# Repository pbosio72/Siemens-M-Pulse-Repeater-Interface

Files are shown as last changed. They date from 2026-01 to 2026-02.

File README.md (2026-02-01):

# Siemens M Pulse Repeater Interface
# Interfaccia per Ripetitore di Impulsi Siemens M

[English](#english) | [Italiano](#italiano)

---

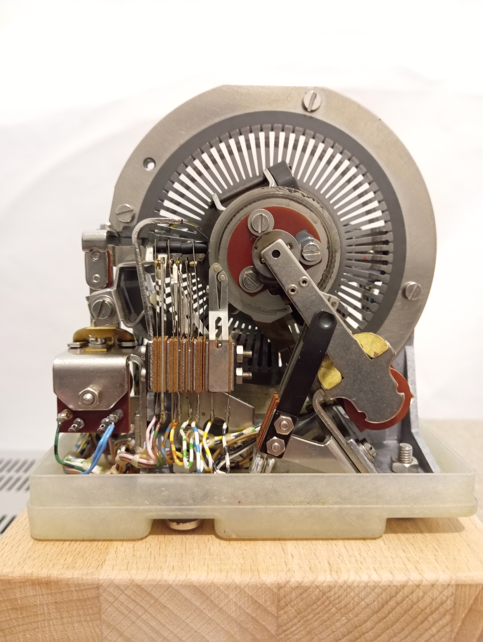
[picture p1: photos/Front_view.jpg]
Siemens Pulse Repeater Front View

*Front view of the Siemens M pulse repeater*

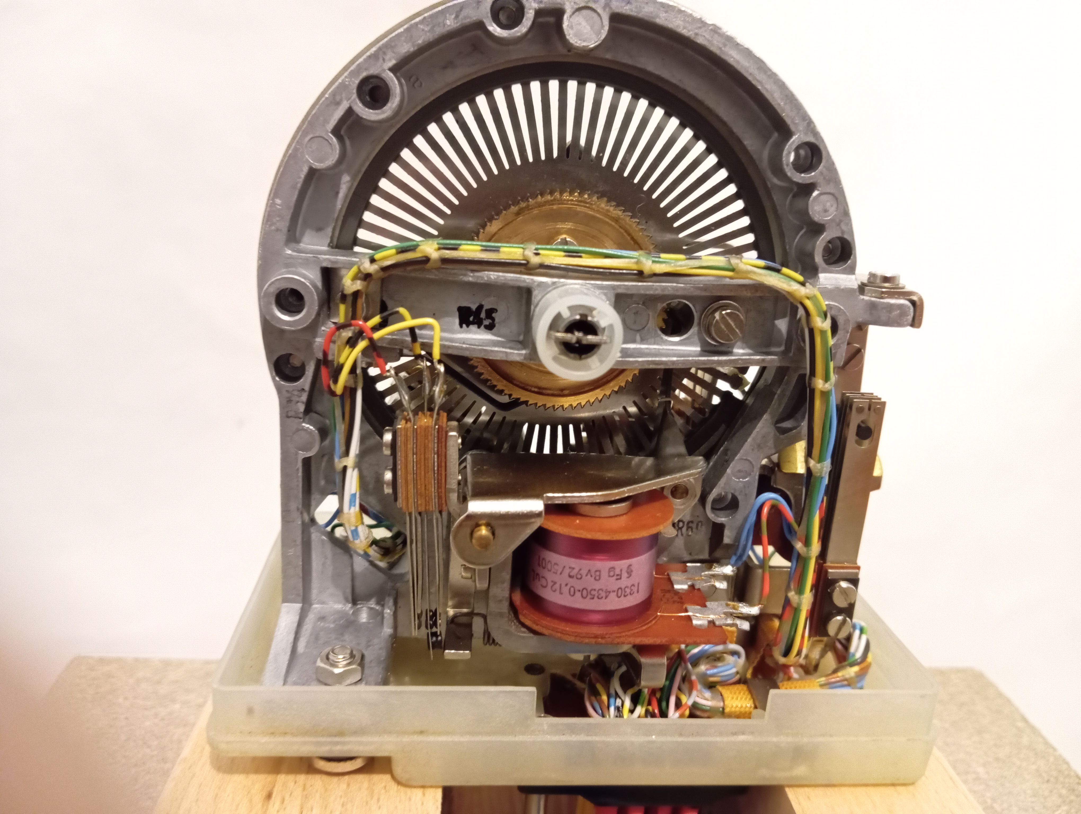
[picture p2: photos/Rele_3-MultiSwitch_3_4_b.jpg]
Siemens Pulse Repeater Rear View

*Rear view showing relays and connections*

---

## English

### Overview
This project documents and provides an interface for the Siemens pulse repeater used in "M System" automatic telephone exchanges. The pulse repeater is an electromechanical memory device that served as a temporary register to store telephone number digits in the form of consecutive pulse trains.

This repository includes:
- Complete pinout mapping and functional logic documentation
- Arduino interface for controlling inputs and reading outputs
- Educational demonstrator using numeric keypad input and display output
- Historical documentation and photographs

### Historical Context
The Siemens pulse repeater was introduced in Italian automatic telephone exchanges (SIP) in 1957 and remained in service until approximately 1975, when electronic exchanges began to replace electromechanical systems. 

This device can be considered an electromechanical FIFO memory or circular shift register. Its ingenious construction uses a rotating metal disk divided into thin lamellae, each capable of two stable positions (comparable to 0 and 1): "behind" or "in front of" a ring-shaped track with a reading contact.

Similar electromechanical memories were used in early computers such as the IBM 602 (1946-48) and the IBM 421 tabulator (1950).

### Project Structure
```
.
├── docs/                    # Documentation and datasheets
│   └── historical/         # Historical documents and references
├── technic/                 # Technical documentation
│   ├── pinout/             # Pin mapping and connections
│   └── components/         # Memory components
├── photos/                  # Photographs of the device
├── arduino/                 # Arduino interface code
│   ├── examples/           # Example sketches
│   └── libraries/          # Custom libraries
└── README.md
```

### Hardware Requirements
- Siemens M Pulse Repeater
- Arduino M0 (or compatible boards: Uno, Mega, Nano, etc.)
- Numeric keypad (input device)
- Display (TBD - output device)
- Interface components (relays, drivers, optoisolators - see hardware documentation)
- Power supply (appropriate voltage for the pulse repeater)

---

## ⚠️ POWER SUPPLY AND SAFETY WARNING

### 🔴 CRITICAL SAFETY INFORMATION - READ BEFORE BUILDING

This system requires **TWO separate power supplies**:

#### 1. LOW VOLTAGE SECTION (5V DC)
- Arduino board
- LCD2004 display
- MCP23017 I2C expander
- Digital signal lines
- Control circuitry

#### 2. HIGH VOLTAGE SECTION (48V DC)
- Relay coils
- Mechanical memory actuation system
- Motor drives

### ELECTRICAL ISOLATION

The 5V and 48V sections **MUST** be electrically isolated:
- Relays provide optical or magnetic isolation between sections
- Arduino controls relay coils (low voltage side)
- Relay contacts switch high voltage power
- **NEVER** connect 48V directly to Arduino pins
- Use optocouplers or relay modules with built-in isolation

### WIRING REQUIREMENTS
- Use appropriate wire gauge for 48V current levels
- Ensure proper insulation on all 48V connections
- Keep 48V wiring separate from 5V signal wiring
- Use terminal blocks or connectors rated for 48V
- Implement proper grounding for safety

---

## ⚡ DANGER - HIGH VOLTAGE WARNING

### 48V DC CAN BE LETHAL UNDER CERTAIN CONDITIONS

- 48V DC can cause electrical shock and serious injury
- Risk increases with wet conditions or broken skin
- Can cause burns, muscle contractions, and cardiac effects
- Always disconnect power before handling circuits
- Use insulated tools when working with live circuits
- Never work on circuits while powered
- Ensure all connections are properly insulated
- Keep work area dry

---

## 📜 DISCLAIMER

**The author(s) of this project DISCLAIM ALL RESPONSIBILITY and LIABILITY for any injury, death, property damage, or other consequences resulting from the construction, modification, or use of this system.**

By building or using this project, you acknowledge that:
- ✓ You understand the risks involved with high voltage systems
- ✓ You have the necessary skills and knowledge to work safely
- ✓ You accept full responsibility for your safety and others
- ✓ You will comply with all local electrical codes and regulations
- ✓ You use this information entirely at your own risk

### ⛔ IF YOU ARE NOT QUALIFIED TO WORK WITH HIGH VOLTAGE SYSTEMS, DO NOT ATTEMPT TO BUILD THIS PROJECT.

Consult a qualified electrician or engineer if you have any doubts about electrical safety or proper construction techniques.

---

## 🛡️ RECOMMENDED SAFETY PRACTICES

1. **ALWAYS** disconnect power before touching any part of the circuit
2. Use a multimeter to verify circuits are de-energized
3. Wait for capacitors to discharge before handling
4. Implement emergency stop switch (easily accessible)
5. Use proper enclosure to prevent accidental contact
6. Label all high voltage sections clearly
7. Use appropriate personal protective equipment (PPE)
8. Never bypass safety interlocks or fuses
9. Keep flammable materials away from electrical components
10. Have fire extinguisher suitable for electrical fires nearby

### COMPONENT RATINGS
- Verify current ratings exceed maximum load
- Use fuses or circuit breakers for overcurrent protection
- Select wire gauge appropriate for current and voltage
- Use connectors and terminals rated for the application

### TESTING PROCEDURE
1. Inspect all connections before applying power
2. Test 5V section first (Arduino and logic circuits)
3. With 48V disconnected, verify relay operation (clicking sound)
4. Connect 48V with load disconnected
5. Measure voltages at all test points
6. Connect load only after verifying all safety checks
7. Monitor system during initial operation

### LOCAL REGULATIONS
- Check local electrical codes and regulations
- Some jurisdictions may require certified installation
- Building permits may be required
- Industrial safety standards may apply (OSHA, IEC, etc.)
- Comply with all applicable laws and standards

---

### Current Status
- ✅ Reverse engineering completed
- ✅ Pinout and functional logic documented
- 🔄 Arduino interface testing in progress
- ⏳ Input/output devices integration (planned)
- ⏳ Educational demonstrator assembly (planned)

### Getting Started
_(Documentation will be added as the project progresses)_

1. Review the pinout documentation in `/technic/pinout/`
2. Check the interface schematics in `/technic/components/`
3. Upload the Arduino sketch from `/arduino/examples/`
4. Connect the hardware according to the wiring diagram
5. Test with the provided examples

### Educational Demonstrator
The final goal is to create an educational demonstrator where:
- **Input:** Data is entered via numeric keypad (simulating telephone dialing)
- **Memory:** The pulse repeater stores the digit sequence
- **Output:** The stored data is displayed on an output device

This demonstrates the working principle of electromechanical memories used in mid-20th century telecommunications.

### Contributing
Contributions are welcome! This project aims to preserve and document historical telecommunications technology. Feel free to:
- Submit improvements to documentation
- Share additional historical information or photographs
- Propose interface enhancements
- Report issues or suggest features

### License
This project is released under an open-source license (TBD).

### References
- Foddis, *Corso teorico-pratico di Telefonia*, 2nd ed., Hoepli, 1972 (pp. 150+)
- Luceri, *Il telefono*, Editoriale Delfino, 1970

### Acknowledgments
This project documents technology developed by Siemens for SIP (Società Italiana per l'Esercizio Telefonico) and used in Italian telephone exchanges from 1957 to approximately 1975.

---

## Italiano

### Panoramica
Questo progetto documenta e fornisce un'interfaccia per il ripetitore di impulsi Siemens utilizzato nelle centrali telefoniche automatiche "sistema M". Il ripetitore di impulsi è un dispositivo di memoria elettromeccanica che fungeva da registro temporaneo per memorizzare le cifre del numero telefonico sotto forma di treni di impulsi consecutivi.

Questo repository include:
- Mappatura completa dei pin e documentazione della logica funzionale
- Interfaccia Arduino per comandare gli input e leggere gli output
- Dimostratore educativo con input da tastierino numerico e output su display
- Documentazione storica e fotografie

### Contesto Storico
Il ripetitore di impulsi Siemens fu introdotto nelle centrali telefoniche automatiche italiane (SIP) nel 1957 e rimase in servizio fino al 1975 circa, quando le centrali elettroniche iniziarono a sostituire i sistemi elettromeccanici.

Questo dispositivo può essere considerato una memoria FIFO elettromeccanica o un registro circolare a scorrimento. La sua costruzione ingegnosa utilizza un disco metallico rotante suddiviso in lamelle sottili, ciascuna capace di due posizioni stabili (paragonabili a 0 e 1): "dietro" o "davanti" ad una pista di forma anulare con un contatto di lettura.

Memorie elettromeccaniche simili furono utilizzate nei primi calcolatori come l'IBM 602 (1946-48) e la tabulatrice IBM 421 (1950).

### Struttura del Progetto
```
.
├── docs/                    # Documentazione e datasheet
│   └── historical/         # Documenti storici e riferimenti
├── technic/                 # Documentazione tecnica
│   ├── pinout/             # Mappatura pin e collegamenti
│   └── components/         # Componenti della memoria
├── photos/                  # Fotografie del dispositivo
├── arduino/                 # Codice interfaccia Arduino
│   ├── examples/           # Sketch di esempio
│   └── libraries/          # Librerie personalizzate
└── README.md
```

### Requisiti Hardware
- Ripetitore di Impulsi Siemens M
- Arduino M0 (o schede compatibili: Uno, Mega, Nano, ecc.)
- Tastierino numerico (dispositivo di input)
- Display (da definire - dispositivo di output)
- Componenti di interfaccia (relè, driver, optoisolatori - vedi documentazione hardware)
- Alimentatore (tensione appropriata per il ripetitore di impulsi)

---

## ⚠️ ALIMENTAZIONE E AVVISO DI SICUREZZA

### 🔴 INFORMAZIONI CRITICHE DI SICUREZZA - LEGGERE PRIMA DI COSTRUIRE

Questo sistema richiede **DUE alimentazioni separate**:

#### 1. SEZIONE A BASSA TENSIONE (5V DC)
- Scheda Arduino
- Display LCD2004
- Espansore I2C MCP23017
- Linee di segnale digitali
- Circuiti di controllo

#### 2. SEZIONE AD ALTA TENSIONE (48V DC)
- Bobine dei relè
- Sistema di attuazione della memoria meccanica
- Azionamenti motori

### ISOLAMENTO ELETTRICO

Le sezioni a 5V e 48V **DEVONO** essere elettricamente isolate:
- I relè forniscono isolamento ottico o magnetico tra le sezioni
- Arduino controlla le bobine dei relè (lato bassa tensione)
- I contatti dei relè commutano l'alimentazione ad alta tensione
- **MAI** collegare i 48V direttamente ai pin di Arduino
- Utilizzare optoisolatori o moduli relè con isolamento integrato

### REQUISITI DI CABLAGGIO
- Utilizzare sezione del cavo appropriata per i livelli di corrente a 48V
- Assicurare un adeguato isolamento su tutte le connessioni a 48V
- Mantenere il cablaggio a 48V separato da quello dei segnali a 5V
- Utilizzare morsettiere o connettori certificati per 48V
- Implementare una corretta messa a terra per la sicurezza

---

## ⚡ PERICOLO - AVVISO ALTA TENSIONE

### 48V DC POSSONO ESSERE LETALI IN DETERMINATE CONDIZIONI

- 48V DC possono causare shock elettrico e gravi lesioni
- Il rischio aumenta in condizioni di umidità o con pelle non integra
- Possono causare ustioni, contrazioni muscolari ed effetti cardiaci
- Scollegare sempre l'alimentazione prima di manipolare i circuiti
- Utilizzare utensili isolati quando si lavora con circuiti sotto tensione
- Non lavorare mai su circuiti alimentati
- Assicurarsi che tutte le connessioni siano adeguatamente isolate
- Mantenere l'area di lavoro asciutta

---

## 📜 DISCLAIMER

**L'autore/gli autori di questo progetto DECLINANO OGNI RESPONSABILITÀ per qualsiasi lesione, morte, danno alla proprietà o altre conseguenze derivanti dalla costruzione, modifica o utilizzo di questo sistema.**

Costruendo o utilizzando questo progetto, riconosci che:
- ✓ Comprendi i rischi connessi ai sistemi ad alta tensione
- ✓ Possiedi le competenze e le conoscenze necessarie per lavorare in sicurezza
- ✓ Ti assumi la piena responsabilità per la tua sicurezza e quella degli altri
- ✓ Rispetterai tutte le normative elettriche locali
- ✓ Utilizzi queste informazioni interamente a tuo rischio

### ⛔ SE NON SEI QUALIFICATO PER LAVORARE CON SISTEMI AD ALTA TENSIONE, NON TENTARE DI COSTRUIRE QUESTO PROGETTO.

Consulta un elettricista o ingegnere qualificato in caso di dubbi sulla sicurezza elettrica o sulle corrette tecniche di costruzione.

---

## 🛡️ PRATICHE DI SICUREZZA RACCOMANDATE

1. **SEMPRE** scollegare l'alimentazione prima di toccare qualsiasi parte del circuito
2. Utilizzare un multimetro per verificare che i circuiti siano de-energizzati
3. Attendere la scarica dei condensatori prima della manipolazione
4. Implementare un interruttore di emergenza (facilmente accessibile)
5. Utilizzare un involucro adeguato per prevenire contatti accidentali
6. Etichettare chiaramente tutte le sezioni ad alta tensione
7. Utilizzare dispositivi di protezione individuale (DPI) appropriati
8. Non bypassare mai gli interblocchi di sicurezza o i fusibili
9. Tenere materiali infiammabili lontani dai componenti elettrici
10. Avere un estintore adatto a incendi elettrici nelle vicinanze

### CARATTERISTICHE DEI COMPONENTI
- Verificare che le correnti nominali superino il carico massimo
- Utilizzare fusibili o interruttori automatici per la protezione da sovracorrente
- Selezionare la sezione del cavo appropriata per corrente e tensione
- Utilizzare connettori e terminali certificati per l'applicazione

### PROCEDURA DI TEST
1. Ispezionare tutte le connessioni prima di applicare l'alimentazione
2. Testare prima la sezione a 5V (Arduino e circuiti logici)
3. Con i 48V scollegati, verificare il funzionamento dei relè (suono di scatto)
4. Collegare i 48V con il carico scollegato
5. Misurare le tensioni in tutti i punti di test
6. Collegare il carico solo dopo aver verificato tutti i controlli di sicurezza
7. Monitorare il sistema durante il funzionamento iniziale

### NORMATIVE LOCALI
- Verificare i codici e le normative elettriche locali
- Alcune giurisdizioni potrebbero richiedere installazione certificata
- Potrebbero essere necessari permessi di costruzione
- Potrebbero applicarsi standard di sicurezza industriale (OSHA, IEC, ecc.)
- Rispettare tutte le leggi e gli standard applicabili

---

### Stato Attuale
- ✅ Reverse engineering completato
- ✅ Pinout e logica funzionale documentati
- 🔄 Test interfaccia Arduino in corso
- ⏳ Integrazione dispositivi input/output (pianificata)
- ⏳ Assemblaggio dimostratore educativo (pianificato)

### Come Iniziare
_(La documentazione verrà aggiunta man mano che il progetto progredisce)_

1. Consultare la documentazione del pinout in `/technic/pinout/`
2. Verificare gli schemi dell'interfaccia in `/technic/components/`
3. Caricare lo sketch Arduino da `/arduino/examples/`
4. Collegare l'hardware secondo lo schema di cablaggio
5. Testare con gli esempi forniti

### Dimostratore Educativo
L'obiettivo finale è creare un dimostratore educativo dove:
- **Input:** I dati vengono inseriti tramite tastierino numerico (simulando la composizione telefonica)
- **Memoria:** Il ripetitore di impulsi memorizza la sequenza di cifre
- **Output:** I dati memorizzati vengono visualizzati su un dispositivo di output

Questo dimostra il principio di funzionamento delle memorie elettromeccaniche utilizzate nelle telecomunicazioni della metà del XX secolo.

### Contribuire
I contributi sono benvenuti! Questo progetto mira a preservare e documentare la tecnologia storica delle telecomunicazioni. Sentitevi liberi di:
- Inviare miglioramenti alla documentazione
- Condividere informazioni storiche o fotografie aggiuntive
- Proporre miglioramenti all'interfaccia
- Segnalare problemi o suggerire funzionalità

### Licenza
Questo progetto è rilasciato sotto licenza open-source (da definire).

### Riferimenti
- Foddis, *Corso teorico-pratico di Telefonia*, 2a ed., Hoepli, 1972 (pag. 150 e seguenti)
- Luceri, *Il telefono*, Editoriale Delfino, 1970

### Riconoscimenti
Questo progetto documenta la tecnologia sviluppata da Siemens per la SIP (Società Italiana per l'Esercizio Telefonico) e utilizzata nelle centrali telefoniche italiane dal 1957 al 1975 circa.

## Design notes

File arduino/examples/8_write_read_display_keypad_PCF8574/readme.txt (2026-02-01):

=============================================================================
MECHANICAL MEMORY SYSTEM WITH KEYPAD INPUT - README
=============================================================================

Sketch Name: 8_write_read_display_keypad_PCF8574.ino
Version: 1.0
Date: 2026-02-01
Description: Complete mechanical memory system with 3x4 keypad input via PCF8574

=============================================================================
OVERVIEW
=============================================================================

This sketch implements a complete mechanical memory system with 3x4 matrix keypad
input. Numbers (0-9) are entered via the keypad, converted to 4-bit BCD sequences,
and stored mechanically on a rotating disk. The system uses a PCF8574 I2C expander
to handle the keypad matrix, freeing up Arduino pins for other components.

Key Features:
- 3x4 matrix keypad input via PCF8574 I2C expander (8 I/O pins)
- Real-time digit entry and immediate writing to mechanical memory
- Number to binary (BCD) conversion with 4 bits per digit
- Real-time read and decode display on LCD2004
- Automatic system initialization and head positioning
- Write protection through controlled workflow
- Professional LCD display with status messages
- Visual effects with sliding text and progress indicators

Key Differences from Previous Versions:
- Replaces push buttons with 3x4 matrix keypad
- Uses PCF8574 I2C expander (simpler and cheaper than MCP23017)
- Implements custom keypad scanning function with bitwise operations
- Real-time digit display during read operation
- Enhanced user interface with clear status messages
- Improved timing constants for better user experience
- Removed Serial Monitor dependency (optional debug only)

=============================================================================
POWER SUPPLY AND SAFETY WARNING
=============================================================================

CRITICAL SAFETY INFORMATION - READ BEFORE BUILDING

This system requires TWO separate power supplies:

1. LOW VOLTAGE SECTION (5V DC):
   - Arduino board
   - LCD2004 display
   - MCP23017 I2C expander
   - Digital signal lines
   - Control circuitry

2. HIGH VOLTAGE SECTION (48V DC):
   - Relay coils
   - Mechanical memory actuation system
   - Motor drives

ELECTRICAL ISOLATION:
The 5V and 48V sections MUST be electrically isolated:
- Relays provide optical or magnetic isolation between sections
- Arduino controls relay coils (low voltage side)
- Relay contacts switch high voltage power
- NEVER connect 48V directly to Arduino pins
- Use optocouplers or relay modules with built-in isolation

WIRING REQUIREMENTS:
- Use appropriate wire gauge for 48V current levels
- Ensure proper insulation on all 48V connections
- Keep 48V wiring separate from 5V signal wiring
- Use terminal blocks or connectors rated for 48V
- Implement proper grounding for safety

** DANGER - HIGH VOLTAGE WARNING **
=============================================================================
48V DC CAN BE LETHAL UNDER CERTAIN CONDITIONS

- 48V DC can cause electrical shock and serious injury
- Risk increases with wet conditions or broken skin
- Can cause burns, muscle contractions, and cardiac effects
- Always disconnect power before handling circuits
- Use insulated tools when working with live circuits
- Never work on circuits while powered
- Ensure all connections are properly insulated
- Keep work area dry

DISCLAIMER:
The author(s) of this project DISCLAIM ALL RESPONSIBILITY and LIABILITY
for any injury, death, property damage, or other consequences resulting
from the construction, modification, or use of this system.

By building or using this project, you acknowledge that:
- You understand the risks involved with high voltage systems
- You have the necessary skills and knowledge to work safely
- You accept full responsibility for your safety and others
- You will comply with all local electrical codes and regulations
- You use this information entirely at your own risk

IF YOU ARE NOT QUALIFIED TO WORK WITH HIGH VOLTAGE SYSTEMS,
DO NOT ATTEMPT TO BUILD THIS PROJECT.

Consult a qualified electrician or engineer if you have any doubts
about electrical safety or proper construction techniques.
=============================================================================

RECOMMENDED SAFETY PRACTICES:

1. ALWAYS disconnect power before touching any part of the circuit
2. Use a multimeter to verify circuits are de-energized
3. Wait for capacitors to discharge before handling
4. Implement emergency stop switch (easily accessible)
5. Use proper enclosure to prevent accidental contact
6. Label all high voltage sections clearly
7. Use appropriate personal protective equipment (PPE)
8. Never bypass safety interlocks or fuses
9. Keep flammable materials away from electrical components
10. Have fire extinguisher suitable for electrical fires nearby

COMPONENT RATINGS:
- Verify current ratings exceed maximum load
- Use fuses or circuit breakers for overcurrent protection
- Select wire gauge appropriate for current and voltage
- Use connectors and terminals rated for the application

TESTING PROCEDURE:
1. Inspect all connections before applying power
2. Test 5V section first (Arduino and logic circuits)
3. With 48V disconnected, verify relay operation (clicking sound)
4. Connect 48V with load disconnected
5. Measure voltages at all test points
6. Connect load only after verifying all safety checks
7. Monitor system during initial operation

LOCAL REGULATIONS:
- Check local electrical codes and regulations
- Some jurisdictions may require certified installation
- Building permits may be required
- Industrial safety standards may apply (OSHA, IEC, etc.)
- Comply with all applicable laws and standards

=============================================================================
HARDWARE REQUIREMENTS
=============================================================================

Components:
- Arduino Uno (or compatible)
- LCD2004 Display (20x4 with I2C module, address 0x27)
- PCF8574 I2C expander (address 0x20)
- 3x4 Matrix Keypad
- 3 Relays (for mechanical memory actuation)
- 2 Position Switches (CCW limit and read head sensor)
- Mechanical memory disk and head assembly

Pin Configuration:

ARDUINO UNO:
  Digital Pin 6  → Switch A (reserved for future use)
  Digital Pin 7  → Switch B (reserved for future use)
  Digital Pin 8  → Switch C (CCW limit sensor)
  Digital Pin 9  → Read Head Switch
  Digital Pin 10 → Relay 1 (Write bit 1 mechanism)
  Digital Pin 11 → Relay 2 (Head rotation control)
  Digital Pin 12 → Relay 3 (Disk rotation control)
  Arduino UNO
    Analog Pin A4  → I2C SDA (LCD + MCP23017)
    Analog Pin A5  → I2C SCL (LCD + MCP23017)
  Arduino MEGA 2560
    Digital Pin 20  → I2C SDA (LCD + MCP23017)
    Digital Pin 21  → I2C SCL (LCD + MCP23017)
  Arduino M0
    Dedicated Pin

I2C DEVICES:
  LCD2004:  Address 0x27, connected to SDA/SCL
  PCF8574:  Address 0x20, connected to SDA/SCL

3X4 KEYPAD → PCF8574:
Pin out inverted for montability reason
  Physical Pin 1 → P6 (Column 2: keys 2, 5, 8, 0)
  Physical Pin 2 → P5 (Row 1: keys 1, 2, 3)
  Physical Pin 3 → P4 (Column 1: keys 1, 4, 7, *)
  Physical Pin 4 → P3 (Row 4: keys *, 0, #)
  Physical Pin 5 → P2 (Column 3: keys 3, 6, 9, #)
  Physical Pin 6 → P1 (Row 3: keys 7, 8, 9)
  Physical Pin 7 → P0 (Row 2: keys 4, 5, 6)

KEYPAD MATRIX:
       C1(P2)  C2(P0)  C3(P4)
R1(P1)   1        2        3
R2(P6)   4        5        6
R3(P5)   7        8        9
R4(P3)   *        0        #

NOTE: The keypad pin mapping was determined through physical testing with
      a multimeter in continuity mode. Your keypad may have different wiring.

WHY PCF8574 INSTEAD OF MCP23017:
The PCF8574 is more suitable for this project because:
- 8 I/O pins are sufficient (keypad needs only 7 pins)
- Simpler to use (no pin mode configuration needed)
- More cost-effective (~1€ vs ~2-3€)
- Lower power consumption
- Adequate speed for keypad scanning
- Built-in pull-up resistors
The MCP23017 (16 I/O) would be oversized for this application.

=============================================================================
SOFTWARE REQUIREMENTS
=============================================================================

Arduino Libraries (install via Library Manager):
- Wire.h (built-in)
- LiquidCrystal_I2C by Frank de Brabander
- PCF8574 library by Rob Tillaart

Arduino IDE: 1.8.x or 2.x

Installation Steps:
1. Open Arduino IDE
2. Go to Sketch → Include Library → Manage Libraries
3. Search for "LiquidCrystal I2C" and install (by Frank de Brabander)
4. Search for "PCF8574" and install (by Rob Tillaart)
5. Wire.h is included automatically (built-in library)

=============================================================================
HOW IT WORKS
=============================================================================

NUMBER ENCODING (BCD - Binary-Coded Decimal)
Each decimal digit (0-9) is converted to 4 bits:
  0 → 0000    5 → 0101
  1 → 0001    6 → 0110
  2 → 0010    7 → 0111
  3 → 0011    8 → 1000
  4 → 0100    9 → 1001

Example: User enters "102"
  1 → 0001
  0 → 0000
  2 → 0010
  Result stored in memory: 000100000010 (12 bits total)

KEYPAD SCANNING MECHANISM:
The system uses matrix scanning to detect keypresses with PCF8574:
1. All 8 pins are written simultaneously using pcf.write8()
2. Each row is activated (set LOW) one at a time using bitwise operations
3. All columns are read simultaneously using pcf.read8()
4. If a column reads LOW while a row is active, that key is pressed
5. Key position is determined by row-column intersection
6. Debouncing prevents multiple triggers from single press

PCF8574 ADVANTAGES FOR KEYPAD SCANNING:
- Built-in pull-up resistors (no external resistors needed)
- 8-bit read/write operations are atomic (no timing issues)
- Simple bitwise manipulation for row activation
- Adequate speed for human input (no latency issues)
- Interrupt capability available (not used in this implementation)

WRITE PROCESS:
1. System auto-initializes and positions head at CCW (counter-clockwise) block
2. User presses numeric keys (0-9) on keypad
3. LCD displays "Input Sequence" with digits as they are entered
4. Each digit is IMMEDIATELY converted to 4 bits and written to memory
5. Display shows progress: "X/15" (current digit / maximum)
6. Maximum 15 digits can be entered (60 bits total)
7. User can press * at any time to reset and start over

IMMEDIATE WRITE OPERATION:
Unlike previous versions that stored digits then wrote them all at once,
this version writes each digit to memory immediately after entry:
- Press "1" → converts to 0001 → writes 4 bits → done
- Press "0" → converts to 0000 → writes 4 bits → done
- Press "2" → converts to 0010 → writes 4 bits → done
This prevents data loss and provides instant feedback.

READ PROCESS:
1. User presses # key to initiate read
2. System performs finalization moves:
   - Extra disk rotation to complete last write
   - Head moves back one position for alignment
3. LCD displays "Read Data" with "-> " prompt
4. System reads bits from memory sequentially
5. Every 4 bits are decoded to a decimal digit
6. Decoded digit appears on LCD IMMEDIATELY (real-time display)
7. Digits fill the display left-to-right, line by line
8. Display shows "Done" when read completes
9. System returns to input mode

REAL-TIME DECODE DISPLAY:
The read operation displays decoded numbers as they are read:
  Line 0: "     Read Data"
  Line 2: "-> 0123456789012"  (digits appear one by one)
  Line 3: "                Done"

Maximum 17 digits can be displayed on line 2 (20 chars - "-> " = 17)
If more digits exist, they wrap to line 3.

RESET FUNCTION (* key):
1. Displays "Reset System" message
2. Repositions head to CCW block (same as startup)
3. Clears all entered digits
4. Resets digit counter
5. Displays welcome screen
6. Returns to input mode

MECHANICAL SYNCHRONIZATION:
After the last digit is entered and before reading:
  activateRele(rele_3, sleep_time_rotate);  // Extra disk rotation
  activateRele(rele_2, sleep_time_read);    // Head back one position
This compensates for positioning offset during write operations and
ensures the read head is aligned properly with the first stored bit.

=============================================================================
USAGE INSTRUCTIONS
=============================================================================

STEP 1: Power Up & Initialization
- Connect Arduino to power
- LCD displays "System starting..."
- System automatically positions head to CCW block
- LCD shows "Reset System" during positioning
- LCD displays "Siemens Memory Ready" when complete
- After 3 seconds, shows:
    Line 0: "   Input Sequence"
    Line 2: "Enter digits 0-9"
    Line 3: " *->Reset    #->Read"
- System is now ready for input

STEP 2: Enter Numbers (Keys 0-9)
- Press any digit key (0-9) on keypad
- LCD updates to show:
    Line 0: "   Input Sequence"
    Line 1: "-> [your digits]"
    Line 3: "Writing Memory..."
- Digit is immediately written to memory (4 bits)
- Progress indicator appears: "X/15"
- Continue entering digits (maximum 15)
- Each digit is written immediately - no need to press "enter"

Example sequence for entering "1234":
  Press 1 → LCD shows "-> 1" → writes 0001 to memory → shows "1/15"
  Press 2 → LCD shows "-> 12" → writes 0010 to memory → shows "2/15"
  Press 3 → LCD shows "-> 123" → writes 0011 to memory → shows "3/15"
  Press 4 → LCD shows "-> 1234" → writes 0100 to memory → shows "4/15"

STEP 3: Reset System (Key *)
- Press * at any time to reset
- LCD displays "Reset System"
- Head returns to CCW position
- All entered digits are cleared
- System returns to input mode
- Use this to start over with a new number

STEP 4: Read Data (Key #)
- After entering digits, press # to read
- LCD clears and shows "Read Data"
- System performs alignment moves (disk forward, head back)
- Digits appear one by one on Line 2: "-> 0123456789"
- Each group of 4 bits is decoded and displayed immediately
- Watch the digits appear in real-time as memory is read
- After read completes, "Done" appears on Line 3
- Display shows result for 5 seconds
- System automatically returns to input mode for next sequence

STEP 5: Decode Output (Automatic)
The system automatically decodes 4-bit sequences to decimal:
  Memory: 0001 0000 0010
  Display: "-> 102"
No manual decoding needed - digits appear correctly on LCD.

=============================================================================
LCD DISPLAY MESSAGES
=============================================================================

Startup & Initialization:
"System starting..."       - Arduino boot sequence
"Reset System"             - Positioning head to start
"Siemens Memory Ready"     - System initialized (sliding text effect)
"Enter digits 0-9"         - Instructions
" *->Reset    #->Read"     - Key functions

Input Mode:
"   Input Sequence"        - Main header during input
"-> [digits]"              - Shows entered digits (line 1)
"Writing Memory..."        - Brief status during write
"X/15"                     - Progress indicator (X = current, 15 = max)
"Max digits reached!"      - Cannot enter more than 15 digits

Reset Operation:
"Reset System"             - System is resetting
(then returns to startup sequence)

Read Operation:
"     Read Data"           - Read operation header
"-> [decoded digits]"      - Decoded numbers appear here
"                Done"     - Read operation complete

Error Messages:
"No data available!"       - Attempted read with disk at end position
"No data to read!"         - Pressed # without entering any digits
"PCF8574 ERROR!"          - PCF8574 not detected (halts execution)

=============================================================================
CONFIGURATION PARAMETERS
=============================================================================

Timing Constants (in milliseconds):
  sleep_time_rotate = 100;  // Disk rotation timing
  sleep_time_write = 100;   // Write operation timing
  sleep_time_read = 100;    // Read operation timing
  delay_small = 200;        // Text display sliding effect
  delay_medium = 2000;      // Status message duration
  delay_long = 3000;        // Important message duration
  delay_huge = 5000;        // Final result display duration

Tuning the Timing Constants:
- sleep_time_* values control mechanical relay actuation
  - Increase if bits are unreliable or mechanisms are slow
  - Decrease for faster operation (after confirming reliability)
  - Typical range: 50-200ms depending on hardware
- delay_* values control LCD message display duration
  - Adjust for preferred user interface speed
  - delay_small affects sliding text speed (character-by-character)
  - delay_huge affects how long final results are shown

Memory Configuration:
  const int max_numbers = 15;  // Maximum digits (15 × 4 = 60 bits)

I2C Addresses:
  LCD2004:  0x27 (or 0x3F for some modules)
  PCF8574:  0x20 (default, configurable with A0/A1/A2 jumpers)

To change LCD address (if 0x27 doesn't work):
  LiquidCrystal_I2C lcd(0x3F, 20, 4);

To change PCF8574 address:
  PCF8574 pcf(0x21);  // Change 0x20 to desired address

Keypad Pin Mapping:
  byte rowPins[ROWS] = {1, 6, 5, 3};  // P1, P6, P5, P3
  byte colPins[COLS] = {2, 0, 4};     // P2, P0, P4

NOTE: These pin assignments are based on physical testing of a specific
      keypad. Different keypad models may have different internal wiring.
      Use a multimeter to verify your keypad's pin configuration.

=============================================================================
TECHNICAL DETAILS
=============================================================================

BINARY CONVERSION ALGORITHM:
The digitToBits() function extracts 4 bits using bitwise operations:
  bits[0] = (num >> 3) & 1;  // Bit 3 (MSB) - weight 8
  bits[1] = (num >> 2) & 1;  // Bit 2 - weight 4
  bits[2] = (num >> 1) & 1;  // Bit 1 - weight 2
  bits[3] = num & 1;         // Bit 0 (LSB) - weight 1

Example for digit 5 (binary 0101):
  5 >> 3 = 0, masked = 0  →  bits[0] = 0
  5 >> 2 = 1, masked = 1  →  bits[1] = 1
  5 >> 1 = 2, masked = 0  →  bits[2] = 0
  5 >> 0 = 5, masked = 1  →  bits[3] = 1
Result: [0, 1, 0, 1] which is 0101 in binary = 5 in decimal

DECODE ALGORITHM (Read Operation):
The readAndDecodeMemory() function converts 4 bits back to decimal:
  for (int j = 0; j < 4; j++) {
    if (fourBits.charAt(j) == '1') {
      decimalValue += (1 << (3 - j));
    }
  }

Example decoding "0101":
  j=0: '0' → skip
  j=1: '1' → add (1 << 2) = 4 → decimalValue = 4
  j=2: '0' → skip
  j=3: '1' → add (1 << 0) = 1 → decimalValue = 5
Result: 5

KEYPAD MATRIX SCANNING:
The scanKeypad() function implements matrix scanning with PCF8574:
1. Prepare byte pattern with all pins HIGH except current row
2. Write pattern to PCF8574 using pcf.write8()
3. Read all pins simultaneously using pcf.read8()
4. Check column pins using bitRead() to detect LOW state
5. If column is LOW, key at (row, column) is pressed
6. Return corresponding character from keys[][] array
7. If no key pressed, return 0

PCF8574 BITWISE OPERATIONS:
  byte rowPattern = 0xFF;              // All pins HIGH (11111111)
  bitClear(rowPattern, rowPins[r]);   // Set row pin LOW
  pcf.write8(rowPattern);             // Write to all 8 pins at once
  byte readValue = pcf.read8();       // Read all 8 pins at once
  if (bitRead(readValue, colPins[c]) == LOW)  // Check column pin

This approach is more efficient than individual pinMode/digitalWrite calls.

Debouncing is implemented by:
- Waiting for key release before returning
- Adding 50ms delay after release
- 5ms stabilization delay between row changes

READ LOGIC INVERSION:
The read head switch uses inverted logic:
  char bit = (!switchState_read) ? '1' : '0';
This is because the mechanical sensor reads:
  HIGH → bit 0
  LOW  → bit 1
So we invert in software to get correct bit values.

WRITE COMPENSATION:
After entering all digits and before reading:
  activateRele(rele_3, sleep_time_rotate);  // Extra disk rotation
  activateRele(rele_2, sleep_time_read);    // Head back one position

This two-step compensation ensures:
1. The last written bit is properly positioned
2. The read head aligns with the first bit for accurate reading

IMMEDIATE WRITE BEHAVIOR:
Each digit is written as soon as its key is pressed:
  writeDigitToMemory(key);  // Called immediately in loop()
This means:
- Data is never lost (written instantly, not buffered)
- User gets immediate feedback via relay sounds
- No need for a separate "write" or "enter" button
- System state is always synchronized with display

=============================================================================
TROUBLESHOOTING
=============================================================================

Problem: "PCF8574 ERROR!" on LCD at startup
Solution:
  - Check PCF8574 power connections (VCC to 5V, GND to GND)
  - Verify I2C connections (SDA to A4, SCL to A5 on Uno)
  - Check I2C address (default 0x20)
  - Run I2C scanner sketch to detect PCF8574
  - Verify PCF8574 is properly seated if using breadboard
  - Check for solder bridges if using custom PCB
  - Verify A0/A1/A2 address pins configuration

Problem: LCD shows text but no keypad response
Solution:
  - Verify keypad is connected to correct PCF8574 pins
  - Check rowPins[] and colPins[] arrays match your keypad
  - Use multimeter to test keypad pin mapping
  - Add debug Serial.print() to scanKeypad() function
  - Test PCF8574 with simple write8/read8 operations
  - Verify built-in pull-ups are working (no external needed)

Problem: Keypad registers wrong keys
Solution:
  - Your keypad has different internal wiring
  - Use multimeter in continuity mode to map pins
  - Update rowPins[] and colPins[] arrays accordingly
  - Update keys[][] array if button layout differs
  - Refer to "Keypad Pin Mapping" section in header

Problem: Keypad registers multiple keys per press
Solution:
  - Increase debounce delay in scanKeypad()
  - Check for electrical noise on connections
  - Add small capacitors (0.1µF) across keypad pins if needed
  - PCF8574 has built-in pull-ups, no external resistors needed
  - Reduce scan speed (increase delay between pcf.write8() and pcf.read8())

Problem: LCD backlight on but no text
Solution:
  - Adjust contrast potentiometer on I2C module
  - Use small screwdriver on blue component on back
  - Turn slowly until text appears
  - Try changing I2C address to 0x3F

Problem: System doesn't reset properly
Solution:
  - Check Switch C (CCW limit sensor) is working
  - Verify switch is normally-open type
  - Check wiring and connections
  - Add debug prints to see switch state
  - Manually position head and restart
  - Increase sleep_time_rotate if mechanism is slow

Problem: Incorrect bits read from memory
Solution:
  - Increase sleep_time_read and sleep_time_rotate
  - Verify read head switch alignment
  - Check inverted logic is correct (!switchState_read)
  - Ensure smooth mechanical movement
  - Add delays between operations
  - Verify write compensation moves are executing

Problem: Not all digits displayed during read
Solution:
  - LCD can show ~17 digits on line 2 (20 chars - "-> ")
  - If entering 15 digits, some will wrap to line 3
  - This is normal behavior
  - Reduce number of input digits if full visibility needed
  - Check Serial Monitor for complete sequence

Problem: "Max digits reached!" appears
Solution:
  - This is normal - 15 digit limit has been reached
  - Press * to reset and start new sequence
  - Or press # to read current sequence
  - Adjust max_numbers constant if more digits needed
  - Consider mechanical memory capacity before increasing

Problem: "No data to read!" message
Solution:
  - You pressed # without entering any digits first
  - Enter digits 0-9 before pressing #
  - System prevents reading empty memory

=============================================================================
CODE STRUCTURE
=============================================================================

Main Functions:

Keypad Functions:
- scanKeypad()         : Scan 3x4 matrix and return pressed key

Memory Functions:
- activateRele()       : Pulse relay on/off with timing
- digitToBits()        : Convert decimal digit to 4-bit binary array
- writeSingleBit()     : Write one bit to mechanical memory
- writeDigitToMemory() : Convert digit to bits and write all 4

Display Functions:
- printSlow()          : Display text character-by-character (effect)

System Functions:
- resetSystem()        : Clear sequence and reposition head to CCW
- readAndDecodeMemory(): Read bits and decode to decimal in real-time

Setup Section:
- Initialize all pins (Arduino digital pins)
- Initialize LCD2004 display
- Initialize PCF8574 I2C expander
- Set all PCF8574 pins HIGH initially (ready for keypad scanning)
- Perform initial system reset and head positioning

Loop Section:
- Continuously scan keypad for input
- Handle numeric keys (0-9): add to sequence and write to memory
- Handle * key: reset system
- Handle # key: finalize write and read/decode memory
- Update LCD display with current status
- Implement digit counter and maximum limit

Key Variables:
- inputSequence: String storing entered decimal digits
- digitCount: Counter for number of digits entered
- fourBits: Buffer for accumulating 4 bits during read

=============================================================================
NOTES
=============================================================================

- Maximum 15 decimal digits can be stored (60 bits total)
- LCD2004 can display approximately 17 digits per line
- Only digits 0-9 are supported (alphabetic characters not implemented)
- Each digit is written immediately upon entry (no buffering)
- Keypad pin mapping is specific to tested hardware - verify with multimeter
- System automatically handles write/read synchronization
- PCF8574 shares I2C bus with LCD - different addresses prevent conflicts
- PCF8574 has built-in pull-up resistors - no external resistors needed
- Mechanical timing may require adjustment for different hardware
- Both LCD and Serial Monitor show operation status
- Real-time decode provides instant feedback on stored data

=============================================================================
SUPPORT & ADDITIONAL INFORMATION
=============================================================================

For questions, issues, or improvements:
- Review main project README.md in repository root
- Check wiring diagram in /docs folder
- Test PCF8574 separately with simple I2C scanner
- Verify keypad pin mapping with multimeter
- Test mechanical system independently
- Use Serial Monitor for debugging
- Adjust timing constants for your specific hardware

Keypad Pin Testing Procedure:
1. Set multimeter to continuity mode (beep)
2. Place one probe on keypad pin
3. Place other probe on another keypad pin
4. Press each key systematically
5. Note which key makes the beep for each pin pair
6. Build a matrix showing row/column relationships
7. Update rowPins[] and colPins[] arrays accordingly

I2C Device Testing:
1. Upload I2C scanner sketch to Arduino
2. Open Serial Monitor at 9600 baud
3. Should detect devices at 0x20 (PCF8574) and 0x27 (LCD)
4. If addresses differ, update code accordingly

=============================================================================

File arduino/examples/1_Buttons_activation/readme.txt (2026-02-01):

Buttons activation

**File:** 1_Buttons_activation.ino`

**Purpose:** This is the simplest sketch, providing basic button-to-relay mapping without any display or additional feedback mechanisms.

**Hardware Requirements:**
- 3 push buttons (pins 3, 4, 5)
- 3 relays (pins 10, 11, 12)

**Functionality:**
- **Button 1:** Directly controls Relay 1 (ON when pressed, OFF when released)
- **Button 2:** Directly controls Relay 2 (ON when pressed, OFF when released)
- **Button 3:** Directly controls Relay 3 (ON when pressed, OFF when released)

**Timing Parameters:**
- Relay actuation time: 10ms

**Use Case:** Ideal for basic testing or when no visual feedback is required. Suitable for initial hardware verification.

| Component | Pin Number |
|---|---|
| Button 1  | 3 |
| Button 2  | 4 |
| Button 3  | 5 |
| Switch A  | 6 |
| Switch B  | 7 |
| Switch C  | 8 |
| Relay 1 | 10 |
| Relay 2 | 11 |
| Relay 3 | 12 |

## Libraries Required
- No external libraries required

## Notes

- All sketches initialize relays to the OFF state (LOW) on startup
- Serial communication is initialized at 9600 baud for debugging purposes
- Small delays (1ms) are implemented between pin reads for stability

=============================================================================
POWER SUPPLY AND SAFETY WARNING
=============================================================================

CRITICAL SAFETY INFORMATION - READ BEFORE BUILDING

This system requires TWO separate power supplies:

1. LOW VOLTAGE SECTION (5V DC):
   - Arduino board
   - LCD2004 display
   - MCP23017 I2C expander
   - Digital signal lines
   - Control circuitry

2. HIGH VOLTAGE SECTION (48V DC):
   - Relay coils
   - Mechanical memory actuation system
   - Motor drives

ELECTRICAL ISOLATION:
The 5V and 48V sections MUST be electrically isolated:
- Relays provide optical or magnetic isolation between sections
- Arduino controls relay coils (low voltage side)
- Relay contacts switch high voltage power
- NEVER connect 48V directly to Arduino pins
- Use optocouplers or relay modules with built-in isolation

WIRING REQUIREMENTS:
- Use appropriate wire gauge for 48V current levels
- Ensure proper insulation on all 48V connections
- Keep 48V wiring separate from 5V signal wiring
- Use terminal blocks or connectors rated for 48V
- Implement proper grounding for safety

** DANGER - HIGH VOLTAGE WARNING **
=============================================================================
48V DC CAN BE LETHAL UNDER CERTAIN CONDITIONS

- 48V DC can cause electrical shock and serious injury
- Risk increases with wet conditions or broken skin
- Can cause burns, muscle contractions, and cardiac effects
- Always disconnect power before handling circuits
- Use insulated tools when working with live circuits
- Never work on circuits while powered
- Ensure all connections are properly insulated
- Keep work area dry

DISCLAIMER:
The author(s) of this project DISCLAIM ALL RESPONSIBILITY and LIABILITY
for any injury, death, property damage, or other consequences resulting
from the construction, modification, or use of this system.

By building or using this project, you acknowledge that:
- You understand the risks involved with high voltage systems
- You have the necessary skills and knowledge to work safely
- You accept full responsibility for your safety and others
- You will comply with all local electrical codes and regulations
- You use this information entirely at your own risk

IF YOU ARE NOT QUALIFIED TO WORK WITH HIGH VOLTAGE SYSTEMS,
DO NOT ATTEMPT TO BUILD THIS PROJECT.

Consult a qualified electrician or engineer if you have any doubts
about electrical safety or proper construction techniques.
=============================================================================

RECOMMENDED SAFETY PRACTICES:

1. ALWAYS disconnect power before touching any part of the circuit
2. Use a multimeter to verify circuits are de-energized
3. Wait for capacitors to discharge before handling
4. Implement emergency stop switch (easily accessible)
5. Use proper enclosure to prevent accidental contact
6. Label all high voltage sections clearly
7. Use appropriate personal protective equipment (PPE)
8. Never bypass safety interlocks or fuses
9. Keep flammable materials away from electrical components
10. Have fire extinguisher suitable for electrical fires nearby

COMPONENT RATINGS:
- Verify current ratings exceed maximum load
- Use fuses or circuit breakers for overcurrent protection
- Select wire gauge appropriate for current and voltage
- Use connectors and terminals rated for the application

TESTING PROCEDURE:
1. Inspect all connections before applying power
2. Test 5V section first (Arduino and logic circuits)
3. With 48V disconnected, verify relay operation (clicking sound)
4. Connect 48V with load disconnected
5. Measure voltages at all test points
6. Connect load only after verifying all safety checks
7. Monitor system during initial operation

LOCAL REGULATIONS:
- Check local electrical codes and regulations
- Some jurisdictions may require certified installation
- Building permits may be required
- Industrial safety standards may apply (OSHA, IEC, etc.)
- Comply with all applicable laws and standards

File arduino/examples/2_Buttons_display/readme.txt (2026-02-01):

Button actuation and mini-oled display visual

**File:** `2_Buttons_display.ino`

**Purpose:** This sketch provides direct button-to-relay control while continuously monitoring and displaying the state of three input switches on an OLED display.

**Hardware Requirements:**
- 3 push buttons (pins 3, 4, 5)
- 3 switches for monitoring (pins 6, 7, 8)
- 3 relays (pins 10, 11, 12)
- OLED display (128x64, I2C address 0x3C)

**Functionality:**
- **Button 1:** Directly controls Relay 1 (ON when pressed, OFF when released)
- **Button 2:** Directly controls Relay 2 (ON when pressed, OFF when released)
- **Button 3:** Directly controls Relay 3 (ON when pressed, OFF when released)
- **Continuous monitoring:** Reads the state of switches A, B, and C
- **Display:** Shows real-time status of all three switches (ON/OFF)

**Display Output:**
```
Switch A: ON/OFF
Switch B: ON/OFF
Switch C: ON/OFF
```

**Timing Parameters:**
- Relay actuation time: 10ms
- Reading stability delay: 1ms

## Pin Mapping

| Component | Pin Number |
|---|---|
| Button 1  | 3 |
| Button 2  | 4 |
| Button 3  | 5 |
| Switch A  | 6 |
| Switch B  | 7 |
| Switch C  | 8 |
| Relay 1 | 10 |
| Relay 2 | 11 |
| Relay 3 | 12 |

## Libraries Required
- Wire.h (built-in)
- Adafruit_GFX.h
- Adafruit_SSD1306.h

## Notes

- All sketches initialize relays to the OFF state (LOW) on startup
- Serial communication is initialized at 9600 baud for debugging purposes
- Small delays (1ms) are implemented between pin reads for stability
- OLED display address is set to 0x3C (default for most SSD1306 displays)

=============================================================================
POWER SUPPLY AND SAFETY WARNING
=============================================================================

CRITICAL SAFETY INFORMATION - READ BEFORE BUILDING

This system requires TWO separate power supplies:

1. LOW VOLTAGE SECTION (5V DC):
   - Arduino board
   - LCD2004 display
   - MCP23017 I2C expander
   - Digital signal lines
   - Control circuitry

2. HIGH VOLTAGE SECTION (48V DC):
   - Relay coils
   - Mechanical memory actuation system
   - Motor drives

ELECTRICAL ISOLATION:
The 5V and 48V sections MUST be electrically isolated:
- Relays provide optical or magnetic isolation between sections
- Arduino controls relay coils (low voltage side)
- Relay contacts switch high voltage power
- NEVER connect 48V directly to Arduino pins
- Use optocouplers or relay modules with built-in isolation

WIRING REQUIREMENTS:
- Use appropriate wire gauge for 48V current levels
- Ensure proper insulation on all 48V connections
- Keep 48V wiring separate from 5V signal wiring
- Use terminal blocks or connectors rated for 48V
- Implement proper grounding for safety

** DANGER - HIGH VOLTAGE WARNING **
=============================================================================
48V DC CAN BE LETHAL UNDER CERTAIN CONDITIONS

- 48V DC can cause electrical shock and serious injury
- Risk increases with wet conditions or broken skin
- Can cause burns, muscle contractions, and cardiac effects
- Always disconnect power before handling circuits
- Use insulated tools when working with live circuits
- Never work on circuits while powered
- Ensure all connections are properly insulated
- Keep work area dry

DISCLAIMER:
The author(s) of this project DISCLAIM ALL RESPONSIBILITY and LIABILITY
for any injury, death, property damage, or other consequences resulting
from the construction, modification, or use of this system.

By building or using this project, you acknowledge that:
- You understand the risks involved with high voltage systems
- You have the necessary skills and knowledge to work safely
- You accept full responsibility for your safety and others
- You will comply with all local electrical codes and regulations
- You use this information entirely at your own risk

IF YOU ARE NOT QUALIFIED TO WORK WITH HIGH VOLTAGE SYSTEMS,
DO NOT ATTEMPT TO BUILD THIS PROJECT.

Consult a qualified electrician or engineer if you have any doubts
about electrical safety or proper construction techniques.
=============================================================================

RECOMMENDED SAFETY PRACTICES:

1. ALWAYS disconnect power before touching any part of the circuit
2. Use a multimeter to verify circuits are de-energized
3. Wait for capacitors to discharge before handling
4. Implement emergency stop switch (easily accessible)
5. Use proper enclosure to prevent accidental contact
6. Label all high voltage sections clearly
7. Use appropriate personal protective equipment (PPE)
8. Never bypass safety interlocks or fuses
9. Keep flammable materials away from electrical components
10. Have fire extinguisher suitable for electrical fires nearby

COMPONENT RATINGS:
- Verify current ratings exceed maximum load
- Use fuses or circuit breakers for overcurrent protection
- Select wire gauge appropriate for current and voltage
- Use connectors and terminals rated for the application

TESTING PROCEDURE:
1. Inspect all connections before applying power
2. Test 5V section first (Arduino and logic circuits)
3. With 48V disconnected, verify relay operation (clicking sound)
4. Connect 48V with load disconnected
5. Measure voltages at all test points
6. Connect load only after verifying all safety checks
7. Monitor system during initial operation

LOCAL REGULATIONS:
- Check local electrical codes and regulations
- Some jurisdictions may require certified installation
- Building permits may be required
- Industrial safety standards may apply (OSHA, IEC, etc.)
- Comply with all applicable laws and standards

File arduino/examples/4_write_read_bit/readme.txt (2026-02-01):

# Siemens M Pulse Repeater Interface - Program Explanation

## General Overview

This Arduino program controls the **Siemens M pulse repeater**, an electromechanical memory device that stores bit sequences (0 and 1) on a rotating disk with thin lamellae. The program allows you to:
- **Write** bits to memory
- **Read** bits from memory
- **Display** status on an OLED display

=============================================================================
POWER SUPPLY AND SAFETY WARNING
=============================================================================

CRITICAL SAFETY INFORMATION - READ BEFORE BUILDING

This system requires TWO separate power supplies:

1. LOW VOLTAGE SECTION (5V DC):
   - Arduino board
   - LCD2004 display
   - MCP23017 I2C expander
   - Digital signal lines
   - Control circuitry

2. HIGH VOLTAGE SECTION (48V DC):
   - Relay coils
   - Mechanical memory actuation system
   - Motor drives

ELECTRICAL ISOLATION:
The 5V and 48V sections MUST be electrically isolated:
- Relays provide optical or magnetic isolation between sections
- Arduino controls relay coils (low voltage side)
- Relay contacts switch high voltage power
- NEVER connect 48V directly to Arduino pins
- Use optocouplers or relay modules with built-in isolation

WIRING REQUIREMENTS:
- Use appropriate wire gauge for 48V current levels
- Ensure proper insulation on all 48V connections
- Keep 48V wiring separate from 5V signal wiring
- Use terminal blocks or connectors rated for 48V
- Implement proper grounding for safety

** DANGER - HIGH VOLTAGE WARNING **
=============================================================================
48V DC CAN BE LETHAL UNDER CERTAIN CONDITIONS

- 48V DC can cause electrical shock and serious injury
- Risk increases with wet conditions or broken skin
- Can cause burns, muscle contractions, and cardiac effects
- Always disconnect power before handling circuits
- Use insulated tools when working with live circuits
- Never work on circuits while powered
- Ensure all connections are properly insulated
- Keep work area dry

DISCLAIMER:
The author(s) of this project DISCLAIM ALL RESPONSIBILITY and LIABILITY
for any injury, death, property damage, or other consequences resulting
from the construction, modification, or use of this system.

By building or using this project, you acknowledge that:
- You understand the risks involved with high voltage systems
- You have the necessary skills and knowledge to work safely
- You accept full responsibility for your safety and others
- You will comply with all local electrical codes and regulations
- You use this information entirely at your own risk

IF YOU ARE NOT QUALIFIED TO WORK WITH HIGH VOLTAGE SYSTEMS,
DO NOT ATTEMPT TO BUILD THIS PROJECT.

Consult a qualified electrician or engineer if you have any doubts
about electrical safety or proper construction techniques.
=============================================================================

RECOMMENDED SAFETY PRACTICES:

1. ALWAYS disconnect power before touching any part of the circuit
2. Use a multimeter to verify circuits are de-energized
3. Wait for capacitors to discharge before handling
4. Implement emergency stop switch (easily accessible)
5. Use proper enclosure to prevent accidental contact
6. Label all high voltage sections clearly
7. Use appropriate personal protective equipment (PPE)
8. Never bypass safety interlocks or fuses
9. Keep flammable materials away from electrical components
10. Have fire extinguisher suitable for electrical fires nearby

COMPONENT RATINGS:
- Verify current ratings exceed maximum load
- Use fuses or circuit breakers for overcurrent protection
- Select wire gauge appropriate for current and voltage
- Use connectors and terminals rated for the application

TESTING PROCEDURE:
1. Inspect all connections before applying power
2. Test 5V section first (Arduino and logic circuits)
3. With 48V disconnected, verify relay operation (clicking sound)
4. Connect 48V with load disconnected
5. Measure voltages at all test points
6. Connect load only after verifying all safety checks
7. Monitor system during initial operation

LOCAL REGULATIONS:
- Check local electrical codes and regulations
- Some jurisdictions may require certified installation
- Building permits may be required
- Industrial safety standards may apply (OSHA, IEC, etc.)
- Comply with all applicable laws and standards

## Hardware - Input/Output Pins

### **INPUT PINS - User Buttons**

| Pin | Name | Function |
|-----|---|---|
| 3 | `button_1` | Button to **write bit 1** |
| 4 | `button_2` | Button to **write bit 0** |
| 5 | `button_3` | Button to **read stored data** |

### **INPUT PINS - Position Switches**

| Pin | Name | Function |
|-----|---|---|
| 6 | `switch_A` | Switch A - Disk position detection |
| 7 | `switch_B` | Switch B - Disk position detection |
| 8 | `switch_C` | Switch C - **CCW block** detection (initial position) |
| 9 | `switch_read` | Reading head switch - Reads if lamella is in position 0 or 1 |

**Note:** Switches A, B, C detect when the disk reaches specific positions (likely mechanical blocks that prevent further rotation).

### **OUTPUT PINS - Control Relays**

| Pin | Name | Function |
|-----|---|---|
| 10 | `rele_1` | Relay 1 - **Writes bit 1** (moves lamella to "front" position) |
| 11 | `rele_2` | Relay 2 - **CCW rotation** (counterclockwise) |
| 12 | `rele_3` | Relay 3 - **CW rotation** (clockwise - forward movement) |

---

## Program Logic

### **SETUP - Initialization (executed once at startup)**
```
1. Initialize serial communication (9600 baud)
2. Configure all pins (INPUT/OUTPUT)
3. Turn off all relays (safe state)
4. Initialize OLED display
5. IMPORTANT: Position the disk to initial position (home position)
```

**Home Position Procedure:**
```
a. Read switch_C
b. If switch_C = LOW (disk already at the end):
   - Move 2 steps forward (CW with rele_3)
   - Ensure not on the block
c. Rotate counterclockwise (CCW with rele_2) until switch_C = LOW
d. Now the disk is at initial position (CCW block)
```

---

### **LOOP - Main Cycle (executed continuously)**

#### **1. End of Disk Check**
```cpp
Read: switch_A, switch_B, switch_C
If switch_A = LOW:
  - Display "End of disk!"
  - Set eod_state = 1 (end of disk reached)
Otherwise:
  - eod_state = 0 (can still write)
```

**Why?** Prevents writing beyond the physical disk limit.

---

#### **2. Bit Writing (only if eod_state = 0)**

##### **Write Bit 1 (button_1 pressed):**
```
1. Activate rele_1 (move lamella to position "1")
2. Wait sleep_time_write (60ms)
3. Activate rele_3 (advance disk one position)
4. Deactivate rele_1
5. Display: "Write bit -> 1"
```

**Physical sequence:**
- Electromagnet 1 moves the lamella to the reading track side
- Disk advances one position
- Ready for next write

##### **Write Bit 0 (button_2 pressed):**
```
1. Activate rele_3 (advance disk one position)
2. Display: "Write bit -> 0"
```

**Physical sequence:**
- No lamella is moved (remains in "behind" position)
- Disk advances one position
- The position represents a "0"

---

#### **3. Data Reading (button_3 pressed)**
```
1. Check switch_C:
   - If LOW: display "No data available!!" (already at the end)
   
2. If switch_C = HIGH (there is data):
   WHILE switch_C = HIGH (haven't reached the end):
     a. Read switch_read (lamella in position 0 or 1?)
     b. Print value to serial
     c. Activate rele_2 (rotate disk CCW - back to start)
     d. Recheck switch_C
     e. Display: "Read data..."
```

**Physical sequence:**
- Disk rotates backward (CCW)
- Reading head touches each lamella
- If lamella "front" → switch_read = HIGH (bit 1)
- If lamella "behind" → switch_read = LOW (bit 0)
- Continue until reaching switch_C (initial position)

---

## Simplified Flow Diagram
```
[START]
   ↓
[Initialize Hardware]
   ↓
[Go to Initial Position (Home)]
   ↓
┌──[INFINITE LOOP]────────────────────┐
│                                     │
│ 1. Check End of Disk (switch_A)     │
│    ├─ End? → Block writing          │
│    └─ OK? → Allow writing           │
│                                     │
│ 2. Wait for User Input:             │
│    ├─ Button 1? → Write 1, Advance  │
│    ├─ Button 2? → Write 0, Advance  │
│    └─ Button 3? → Read Backward     │
│                                     │
└─────────────────────────────────────┘
```

---

## Timing Constants
```cpp
sleep_time_rotate = 60ms  // Disk rotation time
sleep_time_write = 60ms   // Lamella writing time
sleep_time_read = 60ms    // Reading time
```

**Important note from code:**
> "Previous tests showed that the disk actuation speed and reading speed must be separate because the disk cannot write Bit 1 at the same speed as disk rotation"

This means that writing bit 1 (lamella movement) is slower than simple rotation, so separate timings are needed.

---

## Usage Example

### **Scenario: Write "101" and read it back**

1. **Startup:** Disk goes to initial position (CCW block)

2. **Write "1":**
   - Press button_1
   - Lamella moved to position "1"
   - Disk advances → Position 1 stored

3. **Write "0":**
   - Press button_2
   - Lamella NOT moved (remains "0")
   - Disk advances → Position 2 stored

4. **Write "1":**
   - Press button_1
   - Lamella moved to position "1"
   - Disk advances → Position 3 stored

5. **Read:**
   - Press button_3
   - Disk rotates backward (CCW)
   - Reading head reads: 1, 0, 1
   - Serial displays: `1`, `0`, `1`

---

## OLED Display - Messages

| Option | Message | When it appears |
|---|---|---|
| 1 | "Initial SetUp..." | During home initialization |
| 2 | "Write bit -> 1" | Writing bit 1 |
| 3 | "Write bit -> 0" | Writing bit 0 |
| 4 | "Read data..." | During reading |
| 5 | "End of disk!" | Disk full (switch_A active) |
| 6 | "No data available!!" | Read attempt on empty disk |

---

## Technical Notes

### **Why 3 relays are needed?**
- **Relay 1:** Electromagnet that physically moves the lamella
- **Relay 2:** Electromagnet that rotates disk CCW (reading/reset)
- **Relay 3:** Electromagnet that rotates disk CW (writing/advancement)

### **Why the delay(1)?**
Digital reading stabilization - prevents incorrect readings due to bouncing or electrical noise.

### **System limitations:**
- FIFO memory (First In, First Out)
- Capacity: 72 positions (lamellae on the disk)
- One write can be read only once (then returns to beginning)
- No selective deletion (only complete reset by returning to start)

---

## Memory Operation Principle

The Siemens pulse repeater is an ingenious electromechanical device:

**Storage mechanism:**
- A rotating metal disk divided into 72 thin lamellae
- Each lamella has two stable positions: "behind" or "in front of" an annular track
- These positions represent binary states: 0 and 1

**Three electromagnets control:**
1. **Writing (Relay 1):** Moves lamella from "behind" (0) to "in front" (1) position
2. **Advancement (Relay 3):** Rotates disk clockwise (forward) one position
3. **Reading/Reset (Relay 2):** Rotates disk counterclockwise (backward)

**Reading mechanism:**
- A reading contact runs along the annular track
- When disk rotates, the contact touches lamellae in "front" position (bit 1)
- Lamellae in "behind" position are not touched (bit 0)

**Example - Storing digit "4":**
- Set 4 consecutive lamellae to position "1"
- When read, 4 consecutive pulses are detected
- This represents the telephone digit "4"

---

## Historical Context

This device was used in Italian telephone exchanges (SIP) from 1957 to approximately 1975. It served as a temporary register to store telephone number digits in the form of consecutive pulse trains, allowing single repetition without redialing.

Similar electromechanical memories were used in early computers such as:
- IBM 602 (1946-48)
- IBM 421 tabulator (1950)

This demonstrator preserves and showcases this historical telecommunications technology for educational purposes.

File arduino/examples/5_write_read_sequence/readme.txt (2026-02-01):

=============================================================================
WRITE/READ SEQUENCE SKETCH - README
=============================================================================

Sketch Name: write_read_sequence.ino
Version: 1.0
Date: 2026-01-10
Description: Complete number encoding and storage system for mechanical memory

=============================================================================
OVERVIEW
=============================================================================

This sketch implements a complete write/read system for a mechanical memory
device. It converts decimal numbers (0-9) into 4-bit BCD sequences and stores
them mechanically on a rotating disk. The stored data can then be read back
and displayed via Serial Monitor.

Key Features:
- Automatic initialization and head positioning
- Number to binary (BCD) conversion
- Sequential bit writing to mechanical memory
- Bit sequence reading with inverted logic
- Write protection flag to prevent accidental overwrites
- Real-time OLED display feedback

=============================================================================
POWER SUPPLY AND SAFETY WARNING
=============================================================================

CRITICAL SAFETY INFORMATION - READ BEFORE BUILDING

This system requires TWO separate power supplies:

1. LOW VOLTAGE SECTION (5V DC):
   - Arduino board
   - LCD2004 display
   - MCP23017 I2C expander
   - Digital signal lines
   - Control circuitry

2. HIGH VOLTAGE SECTION (48V DC):
   - Relay coils
   - Mechanical memory actuation system
   - Motor drives

ELECTRICAL ISOLATION:
The 5V and 48V sections MUST be electrically isolated:
- Relays provide optical or magnetic isolation between sections
- Arduino controls relay coils (low voltage side)
- Relay contacts switch high voltage power
- NEVER connect 48V directly to Arduino pins
- Use optocouplers or relay modules with built-in isolation

WIRING REQUIREMENTS:
- Use appropriate wire gauge for 48V current levels
- Ensure proper insulation on all 48V connections
- Keep 48V wiring separate from 5V signal wiring
- Use terminal blocks or connectors rated for 48V
- Implement proper grounding for safety

** DANGER - HIGH VOLTAGE WARNING **
=============================================================================
48V DC CAN BE LETHAL UNDER CERTAIN CONDITIONS

- 48V DC can cause electrical shock and serious injury
- Risk increases with wet conditions or broken skin
- Can cause burns, muscle contractions, and cardiac effects
- Always disconnect power before handling circuits
- Use insulated tools when working with live circuits
- Never work on circuits while powered
- Ensure all connections are properly insulated
- Keep work area dry

DISCLAIMER:
The author(s) of this project DISCLAIM ALL RESPONSIBILITY and LIABILITY
for any injury, death, property damage, or other consequences resulting
from the construction, modification, or use of this system.

By building or using this project, you acknowledge that:
- You understand the risks involved with high voltage systems
- You have the necessary skills and knowledge to work safely
- You accept full responsibility for your safety and others
- You will comply with all local electrical codes and regulations
- You use this information entirely at your own risk

IF YOU ARE NOT QUALIFIED TO WORK WITH HIGH VOLTAGE SYSTEMS,
DO NOT ATTEMPT TO BUILD THIS PROJECT.

Consult a qualified electrician or engineer if you have any doubts
about electrical safety or proper construction techniques.
=============================================================================

RECOMMENDED SAFETY PRACTICES:

1. ALWAYS disconnect power before touching any part of the circuit
2. Use a multimeter to verify circuits are de-energized
3. Wait for capacitors to discharge before handling
4. Implement emergency stop switch (easily accessible)
5. Use proper enclosure to prevent accidental contact
6. Label all high voltage sections clearly
7. Use appropriate personal protective equipment (PPE)
8. Never bypass safety interlocks or fuses
9. Keep flammable materials away from electrical components
10. Have fire extinguisher suitable for electrical fires nearby

COMPONENT RATINGS:
- Verify current ratings exceed maximum load
- Use fuses or circuit breakers for overcurrent protection
- Select wire gauge appropriate for current and voltage
- Use connectors and terminals rated for the application

TESTING PROCEDURE:
1. Inspect all connections before applying power
2. Test 5V section first (Arduino and logic circuits)
3. With 48V disconnected, verify relay operation (clicking sound)
4. Connect 48V with load disconnected
5. Measure voltages at all test points
6. Connect load only after verifying all safety checks
7. Monitor system during initial operation

LOCAL REGULATIONS:
- Check local electrical codes and regulations
- Some jurisdictions may require certified installation
- Building permits may be required
- Industrial safety standards may apply (OSHA, IEC, etc.)
- Comply with all applicable laws and standards

=============================================================================
HARDWARE REQUIREMENTS
=============================================================================

Components:
- Arduino Uno (or compatible)
- 3 Push Buttons (pins 3, 4, 5)
- 4 Position Switches (pins 6, 7, 8, 9)
- 3 Relays (pins 10, 11, 12)
- OLED Display SSD1306 128x64 I2C (SDA: A4, SCL: A5)
- Mechanical memory disk and head assembly

Pin Configuration:
  Button 1 (Write)     → Pin 3
  Button 2 (Unused)    → Pin 4
  Button 3 (Read)      → Pin 5
  Switch A             → Pin 6
  Switch B             → Pin 7
  Switch C (CCW limit) → Pin 8
  Read Head Switch     → Pin 9
  Relay 1 (Write bit1) → Pin 10
  Relay 2 (Head move)  → Pin 11
  Relay 3 (Disk move)  → Pin 12
  I2C SDA              → A4
  I2C SCL              → A5

Note for IC2 connections
 Arduino UNO
   Analog Pin A4  → I2C SDA (LCD + MCP23017)
   Analog Pin A5  → I2C SCL (LCD + MCP23017)
 Arduino MEGA 2560
   Digital Pin 20  → I2C SDA (LCD + MCP23017)
   Digital Pin 21  → I2C SCL (LCD + MCP23017)
 Arduino M0
   Dedicated Pin
   
=============================================================================
SOFTWARE REQUIREMENTS
=============================================================================

Arduino Libraries (install via Library Manager):
- Wire.h (built-in)
- Adafruit_GFX.h
- Adafruit_SSD1306.h

Arduino IDE: 1.8.x or 2.x

=============================================================================
HOW IT WORKS
=============================================================================

NUMBER ENCODING (BCD - Binary-Coded Decimal)
Each decimal digit is converted to 4 bits:
  0 → 0000    5 → 0101
  1 → 0001    6 → 0110
  2 → 0010    7 → 0111
  3 → 0011    8 → 1000
  4 → 0100    9 → 1001

Example: "102" becomes:
  1 → 0001
  0 → 0000
  2 → 0010
  Result: 000100000010 (12 bits total)

WRITE PROCESS:
1. System auto-initializes and positions head at CCW block
2. User presses Button 1
3. Each digit in myNumber is converted to 4 bits
4. Each bit is written sequentially:
   - Bit 1: Relay 1 ON + Relay 3 pulse (write + rotate)
   - Bit 0: Relay 3 pulse only (rotate)
5. Final compensation: disk advances one step, head moves back one step (see MECHANICAL SYNCHRONIZATION detail)
6. flag_write is set to prevent overwrite

MECHANICAL SYNCHRONIZATION:
After writing, the system performs:
- activateRele(rele_3) → Extra disk rotation
- activateRele(rele_2) → Head moves back one position
This compensates for positioning offset during write operations.

READ PROCESS:
1. User presses Button 3
2. Head/disk rotates (Relay 2) and reads each bit
3. Bit values are read from switch_read (inverted logic)
4. Complete sequence is printed to Serial Monitor
5. flag_write is reset to allow new writes

=============================================================================
USAGE INSTRUCTIONS
=============================================================================

STEP 1: Configure Number to Store
Edit this line in the sketch:
  String myNumber = "0123456789012";  // Max 15 digits (0-9)

STEP 2: Upload & Initialize
- Upload sketch to Arduino
- Display shows "Ready!" then auto-initializes
- Wait for "Ready to write!" message

STEP 3: Write Data
- Press Button 1
- Display shows "Writing sequence..."
- Wait for "Write complete!"
- System locks (prevents accidental overwrite)

STEP 4: Read Data
- Press Button 3
- Display shows "Reading data..."
- Open Serial Monitor (9600 baud)
- Bit sequence appears (e.g., "000100000010")
- Display shows "Read complete!"
- System unlocks for new write

STEP 5: Decode Output
Group bits in sets of 4 and convert to decimal:
  0001 0000 0010
    ↓    ↓    ↓
    1    0    2
  Result: "102"

=============================================================================
DISPLAY MESSAGES
=============================================================================

"Initial SetUp..."         - Positioning head to start position
"Ready to write!"          - System ready for write operation
"Writing sequence..."      - Currently writing bits to memory
"Write complete!"          - Write operation successful
"Write blocked! Read first!" - Attempted write while locked
"Reading data..."          - Currently reading from memory
"Read complete!"           - Read operation successful
"No data available!"       - Disk is at end position

=============================================================================
CONFIGURATION PARAMETERS
=============================================================================

Timing Constants (in milliseconds):
  sleep_time_rotate = 100;  // Disk rotation timing
  sleep_time_write = 100;   // Write operation timing
  sleep_time_read = 100;    // Read operation timing

Adjust these values based on your mechanical system:
- Increase if bits are unreliable
- Decrease for faster operation
- Typical range: 50-200ms

Memory Limits:
  const int max_numbers = 15;  // Maximum digits (15 × 4 = 60 bits)

Write Protection:
  int flag_write = 0;  // 0=write allowed, 1=blocked

=============================================================================
TECHNICAL DETAILS
=============================================================================

BINARY CONVERSION ALGORITHM:
The digitToBits() function extracts 4 bits using bitwise operations:
  bits[0] = (num >> 3) & 1;  // Bit 3 (MSB)
  bits[1] = (num >> 2) & 1;  // Bit 2
  bits[2] = (num >> 1) & 1;  // Bit 1
  bits[3] = num & 1;         // Bit 0 (LSB)

READ LOGIC INVERSION:
The read head switch uses inverted logic:
  Serial.print(!switchState_read);
This is because the mechanical sensor reads:
  HIGH → bit 0
  LOW  → bit 1
So we invert in software.

WRITE COMPENSATION:
At the end of writeNumberSequence():
  activateRele(rele_3, sleep_time_rotate);  // Extra disk rotation
  activateRele(rele_2, sleep_time_read);    // Head back one step
This ensures proper alignment for subsequent read operations.

=============================================================================
SERIAL MONITOR OUTPUT
=============================================================================

Baud Rate: 9600

Example output when reading "102":
  000100000010

To decode:
  Split into 4-bit groups: 0001 | 0000 | 0010
  Convert to decimal: 1, 0, 2
  Result: "102"

=============================================================================
CODE STRUCTURE
=============================================================================

Main Functions:
- activateRele()       : Pulse a relay on/off
- display_option()     : Show message on OLED
- digitToBits()        : Convert digit to 4-bit array
- writeSingleBit()     : Write one bit to memory
- writeNumberSequence(): Write entire number sequence

Setup Section:
- Initialize pins and relays
- Initialize OLED display
- Auto-position head to CCW block
- Display ready message

Loop Section:
- Monitor Button 1: trigger write (if flag_write=0)
- Monitor Button 3: trigger read and reset flag
- Implement write protection logic
- Display operation status

=============================================================================
FUTURE IMPROVEMENTS FOR THIS SKETCH
=============================================================================

Planned enhancements:
- Replace myNumber hardcoded value with keypad input
- Add error detection (parity bit or CRC)
- Display decoded numbers on OLED (not just Serial)

=============================================================================
NOTES
=============================================================================

- Maximum 15 digits can be stored (60 bits total)
- Only digits 0-9 are supported (alphabetic characters not implemented)
- Write operations are blocked after first write until read is performed
- Read operation automatically unlocks system for new writes
- Mechanical timing may need adjustment for different hardware setups
- Serial Monitor must be open at 9600 baud to see read output

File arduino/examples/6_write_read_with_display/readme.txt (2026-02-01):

=============================================================================
WRITE/READ SEQUENCE WITH LCD2004 - README
=============================================================================

Sketch Name: 6_write_read_with_display.ino
Version: 2.0
Date: 2026-01-10
Description: Complete number encoding and storage system with LCD2004 display

=============================================================================
OVERVIEW
=============================================================================

This sketch implements a complete write/read system for a mechanical memory
device. It converts decimal numbers (0-9) into 4-bit BCD sequences and stores
them mechanically on a rotating disk. The stored data can then be read back
and displayed in real-time on the LCD2004 display.

Key Features:
- Automatic initialization and head positioning
- Number to binary (BCD) conversion
- Sequential bit writing to mechanical memory
- Real-time bit display on LCD2004 during read operation
- Bit sequence reading with inverted logic
- Write protection flag to prevent accidental overwrites
- LCD2004 feedback (20 characters x 4 lines)

Key Difference from Previous Version:
- Uses LCD2004 (20x4) instead of OLED SSD1306
- Displays read bits in real-time on LCD as they are read
- Simplified display messages
- Bits appear character by character across 4 lines (80 bits max visible)

=============================================================================
POWER SUPPLY AND SAFETY WARNING
=============================================================================

CRITICAL SAFETY INFORMATION - READ BEFORE BUILDING

This system requires TWO separate power supplies:

1. LOW VOLTAGE SECTION (5V DC):
   - Arduino board
   - LCD2004 display
   - MCP23017 I2C expander
   - Digital signal lines
   - Control circuitry

2. HIGH VOLTAGE SECTION (48V DC):
   - Relay coils
   - Mechanical memory actuation system
   - Motor drives

ELECTRICAL ISOLATION:
The 5V and 48V sections MUST be electrically isolated:
- Relays provide optical or magnetic isolation between sections
- Arduino controls relay coils (low voltage side)
- Relay contacts switch high voltage power
- NEVER connect 48V directly to Arduino pins
- Use optocouplers or relay modules with built-in isolation

WIRING REQUIREMENTS:
- Use appropriate wire gauge for 48V current levels
- Ensure proper insulation on all 48V connections
- Keep 48V wiring separate from 5V signal wiring
- Use terminal blocks or connectors rated for 48V
- Implement proper grounding for safety

** DANGER - HIGH VOLTAGE WARNING **
=============================================================================
48V DC CAN BE LETHAL UNDER CERTAIN CONDITIONS

- 48V DC can cause electrical shock and serious injury
- Risk increases with wet conditions or broken skin
- Can cause burns, muscle contractions, and cardiac effects
- Always disconnect power before handling circuits
- Use insulated tools when working with live circuits
- Never work on circuits while powered
- Ensure all connections are properly insulated
- Keep work area dry

DISCLAIMER:
The author(s) of this project DISCLAIM ALL RESPONSIBILITY and LIABILITY
for any injury, death, property damage, or other consequences resulting
from the construction, modification, or use of this system.

By building or using this project, you acknowledge that:
- You understand the risks involved with high voltage systems
- You have the necessary skills and knowledge to work safely
- You accept full responsibility for your safety and others
- You will comply with all local electrical codes and regulations
- You use this information entirely at your own risk

IF YOU ARE NOT QUALIFIED TO WORK WITH HIGH VOLTAGE SYSTEMS,
DO NOT ATTEMPT TO BUILD THIS PROJECT.

Consult a qualified electrician or engineer if you have any doubts
about electrical safety or proper construction techniques.
=============================================================================

RECOMMENDED SAFETY PRACTICES:

1. ALWAYS disconnect power before touching any part of the circuit
2. Use a multimeter to verify circuits are de-energized
3. Wait for capacitors to discharge before handling
4. Implement emergency stop switch (easily accessible)
5. Use proper enclosure to prevent accidental contact
6. Label all high voltage sections clearly
7. Use appropriate personal protective equipment (PPE)
8. Never bypass safety interlocks or fuses
9. Keep flammable materials away from electrical components
10. Have fire extinguisher suitable for electrical fires nearby

COMPONENT RATINGS:
- Verify current ratings exceed maximum load
- Use fuses or circuit breakers for overcurrent protection
- Select wire gauge appropriate for current and voltage
- Use connectors and terminals rated for the application

TESTING PROCEDURE:
1. Inspect all connections before applying power
2. Test 5V section first (Arduino and logic circuits)
3. With 48V disconnected, verify relay operation (clicking sound)
4. Connect 48V with load disconnected
5. Measure voltages at all test points
6. Connect load only after verifying all safety checks
7. Monitor system during initial operation

LOCAL REGULATIONS:
- Check local electrical codes and regulations
- Some jurisdictions may require certified installation
- Building permits may be required
- Industrial safety standards may apply (OSHA, IEC, etc.)
- Comply with all applicable laws and standards

=============================================================================
HARDWARE REQUIREMENTS
=============================================================================

Components:
- Arduino Uno (or compatible)
- 3 Push Buttons (pins 3, 4, 5)
- 4 Position Switches (pins 6, 7, 8, 9)
- 3 Relays (pins 10, 11, 12)
- LCD2004 Display (20x4 with I2C module, address 0x27)
- Mechanical memory disk and head assembly

Pin Configuration:
  Button 1 (Write)     → Pin 3
  Button 2 (Unused)    → Pin 4
  Button 3 (Read)      → Pin 5
  Switch A             → Pin 6
  Switch B             → Pin 7
  Switch C (CCW limit) → Pin 8
  Read Head Switch     → Pin 9
  Relay 1 (Write bit1) → Pin 10
  Relay 2 (Head move)  → Pin 11
  Relay 3 (Disk move)  → Pin 12
  I2C SDA              → A4
  I2C SCL              → A5
  
Note for IC2 connections
 Arduino UNO
   Analog Pin A4  → I2C SDA (LCD + MCP23017)
   Analog Pin A5  → I2C SCL (LCD + MCP23017)
 Arduino MEGA 2560
   Digital Pin 20  → I2C SDA (LCD + MCP23017)
   Digital Pin 21  → I2C SCL (LCD + MCP23017)
 Arduino M0
   Dedicated Pin

LCD2004 I2C Module:
  VCC → 5V
  GND → GND
  SDA → A4
  SCL → A5

Note: LCD shares I2C bus with future MCP23017 expander (different addresses)

=============================================================================
SOFTWARE REQUIREMENTS
=============================================================================

Arduino Libraries (install via Library Manager):
- Wire.h (built-in)
- LiquidCrystal_I2C.h (by Frank de Brabander)

Arduino IDE: 1.8.x or 2.x

Installation:
1. Open Arduino IDE
2. Go to Sketch → Include Library → Manage Libraries
3. Search for "LiquidCrystal I2C"
4. Install "LiquidCrystal I2C" by Frank de Brabander

=============================================================================
HOW IT WORKS
=============================================================================

NUMBER ENCODING (BCD - Binary-Coded Decimal)
Each decimal digit is converted to 4 bits:
  0 → 0000    5 → 0101
  1 → 0001    6 → 0110
  2 → 0010    7 → 0111
  3 → 0011    8 → 1000
  4 → 0100    9 → 1001

Example: "102" becomes:
  1 → 0001
  0 → 0000
  2 → 0010
  Result: 000100000010 (12 bits total)

WRITE PROCESS:
1. System auto-initializes and positions head at CCW block
2. User presses Button 1
3. LCD displays "Writing data..."
4. Each digit in myNumber is converted to 4 bits
5. Each bit is written sequentially:
   - Bit 1: Relay 1 ON + Relay 3 pulse (write + rotate)
   - Bit 0: Relay 3 pulse only (rotate)
6. Final compensation: disk advances, head moves back
7. LCD displays "Write complete!"
8. flag_write is set to prevent overwrite

READ PROCESS:
1. User presses Button 3
2. LCD clears and prepares to display bits
3. Head/disk rotates (Relay 2) and reads each bit
4. Each bit is displayed IMMEDIATELY on LCD as it's read
5. Bits fill the display left-to-right, top-to-bottom (4 lines x 20 chars)
6. Complete sequence is also printed to Serial Monitor
7. After 5 seconds, LCD shows ready message
8. flag_write is reset to allow new writes

REAL-TIME DISPLAY:
The bits appear on LCD in this pattern:
  Line 0: [20 bits]
  Line 1: [20 bits]
  Line 2: [20 bits]
  Line 3: [20 bits]
Total: 80 bits can be displayed (15 digits = 60 bits fits perfectly)

MECHANICAL SYNCHRONIZATION:
After writing, the system performs:
- activateRele(rele_3) → Extra disk rotation
- activateRele(rele_2) → Head moves back one position
This compensates for positioning offset during write operations.

=============================================================================
USAGE INSTRUCTIONS
=============================================================================

STEP 1: Configure Number to Store
Edit this line in the sketch:
  String myNumber = "0123456789012";  // Max 15 digits (0-9)

STEP 2: Upload & Initialize
- Upload sketch to Arduino
- LCD shows "System starting..."
- System auto-positions head
- LCD displays "Positioning head..."
- Wait for "Ready!" message with button instructions

STEP 3: Write Data
- Press Button 1
- LCD shows "Writing data..."
- Relays activate and write sequence to memory
- LCD shows "Write complete!"
- System locks to prevent accidental overwrite
- LCD prompts "Press Btn3 to read data"

STEP 4: Read Data & View on LCD
- Press Button 3
- LCD clears and begins displaying bits in real-time
- Watch bits appear character by character as memory is read
- Bits fill line by line (20 chars per line, 4 lines total)
- Complete sequence also appears in Serial Monitor (9600 baud)
- After 5 seconds, LCD returns to ready state
- System unlocks for new write operation

STEP 5: Decode Output (if needed)
Group bits in sets of 4 and convert to decimal:
  0001 0000 0010
    ↓    ↓    ↓
    1    0    2
  Result: "102"

=============================================================================
LCD DISPLAY MESSAGES
=============================================================================

Startup Messages:
"System starting..."       - Initial boot
"Positioning head..."      - Auto-positioning to CCW block
"Ready!"                   - System ready
"Btn1: Write"              - Button 1 function
"Btn3: Read & Display"     - Button 3 function

Write Operation:
"Writing data..."          - Currently writing to memory
"Write complete!"          - Write operation successful
"Press Btn3"               - Prompt to read data
"to read data"             

Write Protection:
"Write blocked!"           - Attempted write while locked
"Read data first!"         - Instructions to unlock

Read Operation:
[Real-time bit display]    - Bits appear as 1s and 0s
(No text message during read - only bits)

After Read:
"Ready!"                   - System ready again
"Btn1: Write"              - Can write new data
"Btn3: Read & Display"     - Can read again

Error Messages:
"No data available!"       - Disk is already at end position

=============================================================================
CONFIGURATION PARAMETERS
=============================================================================

Timing Constants (in milliseconds):
  sleep_time_rotate = 100;  // Disk rotation timing
  sleep_time_write = 100;   // Write operation timing
  sleep_time_read = 100;    // Read operation timing

Adjust these values based on your mechanical system:
- Increase if bits are unreliable
- Decrease for faster operation
- Typical range: 50-200ms

Memory Limits:
  const int max_numbers = 15;  // Maximum digits (15 × 4 = 60 bits)

Write Protection:
  int flag_write = 0;  // 0=write allowed, 1=blocked

LCD Display Settings:
  LiquidCrystal_I2C lcd(0x27, 20, 4);
  - I2C Address: 0x27 (or 0x3F for some modules)
  - Columns: 20
  - Rows: 4

To Change LCD I2C Address:
If display doesn't work, try changing to 0x3F:
  LiquidCrystal_I2C lcd(0x3F, 20, 4);

To Find Your LCD Address:
Use an I2C scanner sketch to detect the correct address.

Display Timing:
  delay(5000);  // Show read result for 5 seconds
Adjust this value to show results longer or shorter.

=============================================================================
TECHNICAL DETAILS
=============================================================================

BINARY CONVERSION ALGORITHM:
The digitToBits() function extracts 4 bits using bitwise operations:
  bits[0] = (num >> 3) & 1;  // Bit 3 (MSB)
  bits[1] = (num >> 2) & 1;  // Bit 2
  bits[2] = (num >> 1) & 1;  // Bit 1
  bits[3] = num & 1;         // Bit 0 (LSB)

READ LOGIC INVERSION:
The read head switch uses inverted logic:
  int bitValue = !switchState_read;
This is because the mechanical sensor reads:
  HIGH → bit 0
  LOW  → bit 1
So we invert in software.

REAL-TIME LCD DISPLAY ALGORITHM:
During read, bits are displayed character by character:
  int currentLine = 0;   // Start at line 0
  int currentPos = 0;    // Start at position 0
  
  For each bit read:
    lcd.setCursor(currentPos, currentLine);
    lcd.print(bitValue);
    currentPos++;
    if (currentPos >= 20) {  // End of line reached
      currentPos = 0;         // Reset to start
      currentLine++;          // Move to next line
    }

Maximum 80 bits can be displayed (4 lines × 20 chars).
With 15 digits maximum (60 bits), all data fits on display.

WRITE COMPENSATION:
At the end of writeNumberSequence():
  activateRele(rele_3, sleep_time_rotate);  // Extra disk rotation
  activateRele(rele_2, sleep_time_read);    // Head back one step
This ensures proper alignment for subsequent read operations.

=============================================================================
TROUBLESHOOTING
=============================================================================

Problem: LCD backlight on but no text visible
Solution:
  - Adjust contrast potentiometer on I2C module backpack (blue component)
  - Use small screwdriver to turn clockwise/counterclockwise
  - Text should become visible when properly adjusted

Problem: LCD shows no backlight or text
Solution:
  - Check I2C connections (SDA→A4, SCL→A5, VCC→5V, GND→GND)
  - Verify I2C address (try 0x3F if 0x27 doesn't work)
  - Run I2C scanner sketch to detect address
  - Check 5V power supply is adequate

Problem: Bits read incorrectly
Solution:
  - Increase timing values (sleep_time_read, sleep_time_rotate)
  - Verify switch_read sensor alignment
  - Check inverted logic is correct (!switchState_read)
  - Ensure smooth mechanical movement

Problem: System doesn't initialize
Solution:
  - Check Switch C is working (CCW limit)
  - Verify Relay 2 and 3 connections
  - Manually position head at CCW, restart
  - Monitor Serial output for errors

Problem: "Write blocked!" message appears
Solution:
  - This is normal after writing
  - Press Button 3 to read first
  - Reading resets flag_write

Problem: Bits appear garbled on LCD
Solution:
  - Check Serial Monitor output - does it look correct?
  - If Serial is correct but LCD is wrong, reduce read speed
  - Increase delay between bit reads
  - Check LCD refresh rate

Problem: Not all bits displayed on LCD
Solution:
  - LCD can show 80 bits maximum (4 lines × 20 chars)
  - Reduce myNumber length to 15 digits or less
  - Check bitSequence string length in Serial Monitor

=============================================================================
SERIAL MONITOR OUTPUT
=============================================================================

Baud Rate: 9600

Example session when writing/reading "102":

Starting...
LCD initialized
Positioning head...
Ready!
Writing sequence...
Write complete!
Reading data...
000100000010
Bit sequence: 000100000010

To decode:
  Split into 4-bit groups: 0001 | 0000 | 0010
  Convert to decimal: 1, 0, 2
  Result: "102"

=============================================================================
CODE STRUCTURE
=============================================================================

Main Functions:
- activateRele()       : Pulse a relay on/off
- digitToBits()        : Convert digit to 4-bit array
- writeSingleBit()     : Write one bit to memory
- writeNumberSequence(): Write entire number sequence
- displayBitSequence() : Display bits on LCD (not used in real-time version)

Setup Section:
- Initialize pins and relays
- Initialize LCD2004 display with backlight
- Auto-position head to CCW block
- Display ready message with instructions

Loop Section:
- Monitor Button 1: trigger write (if flag_write=0)
- Monitor Button 3: trigger read with real-time LCD display
- Implement write protection logic
- Display operation status on LCD

Real-Time Display Section (in read loop):
- Track current line and position on LCD
- Display each bit immediately as it's read
- Automatically wrap to next line after 20 characters
- Store complete sequence in bitSequence string

=============================================================================
VERSION HISTORY
=============================================================================

v2.0 (2026-01-10)
  - Replaced OLED SSD1306 with LCD2004
  - Implemented real-time bit display during read
  - Simplified display messages
  - Removed displayBitSequence() function (not needed)
  - Added Serial debug messages
  - Added LCD contrast troubleshooting notes

v1.0 (2026-01-10)
  - Initial working version with OLED
  - BCD encoding implementation
  - Write protection flag system
  - Mechanical compensation

=============================================================================
NOTES
=============================================================================

- Maximum 15 digits can be stored (60 bits total)
- LCD can display up to 80 bits (all 4 lines filled)
- Only digits 0-9 are supported (alphabetic characters not implemented)
- Write operations are blocked after first write until read is performed
- Read operation automatically unlocks system for new writes
- Mechanical timing may need adjustment for different hardware setups
- Both Serial Monitor and LCD show the read data
- LCD provides better visualization than Serial for bit sequences
- Contrast adjustment is critical for LCD visibility

=============================================================================
SUPPORT
=============================================================================

For issues, questions, or improvements:
- Check main project README.md in repository root
- Review wiring diagram in /docs folder
- Test with simpler sketches (simple_relay_control.ino) first
- Verify mechanical system operation independently
- Use Serial Monitor for debugging
- Adjust LCD contrast if text not visible

=============================================================================

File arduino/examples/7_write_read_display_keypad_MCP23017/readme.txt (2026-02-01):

=============================================================================
MECHANICAL MEMORY SYSTEM WITH KEYPAD INPUT - README
=============================================================================

Sketch Name: 7_write_read_display_keypad_Arduino_UNO.ino
Version: 1.0
Date: 2026-02-01
Description: Complete mechanical memory system with 3x4 keypad input via MCP23017

=============================================================================
OVERVIEW
=============================================================================

This sketch implements a complete mechanical memory system with 3x4 matrix keypad
input. Numbers (0-9) are entered via the keypad, converted to 4-bit BCD sequences,
and stored mechanically on a rotating disk. The system uses an MCP23017 I2C expander
to handle the keypad matrix, freeing up Arduino pins for other components.

Key Features:
- 3x4 matrix keypad input via MCP23017 I2C expander
- Real-time digit entry and immediate writing to mechanical memory
- Number to binary (BCD) conversion with 4 bits per digit
- Real-time read and decode display on LCD2004
- Automatic system initialization and head positioning
- Write protection through controlled workflow
- Professional LCD display with status messages
- Visual effects with sliding text and progress indicators

Key Differences from Previous Versions:
- Replaces push buttons with 3x4 matrix keypad
- Uses MCP23017 I2C expander for keypad interfacing
- Implements custom keypad scanning function
- Real-time digit display during read operation
- Enhanced user interface with clear status messages
- Improved timing constants for better user experience
- Removed Serial Monitor dependency (optional debug only)

=============================================================================
POWER SUPPLY AND SAFETY WARNING
=============================================================================

CRITICAL SAFETY INFORMATION - READ BEFORE BUILDING

This system requires TWO separate power supplies:

1. LOW VOLTAGE SECTION (5V DC):
   - Arduino board
   - LCD2004 display
   - MCP23017 I2C expander
   - Digital signal lines
   - Control circuitry

2. HIGH VOLTAGE SECTION (48V DC):
   - Relay coils
   - Mechanical memory actuation system
   - Motor drives

ELECTRICAL ISOLATION:
The 5V and 48V sections MUST be electrically isolated:
- Relays provide optical or magnetic isolation between sections
- Arduino controls relay coils (low voltage side)
- Relay contacts switch high voltage power
- NEVER connect 48V directly to Arduino pins
- Use optocouplers or relay modules with built-in isolation

WIRING REQUIREMENTS:
- Use appropriate wire gauge for 48V current levels
- Ensure proper insulation on all 48V connections
- Keep 48V wiring separate from 5V signal wiring
- Use terminal blocks or connectors rated for 48V
- Implement proper grounding for safety

** DANGER - HIGH VOLTAGE WARNING **
=============================================================================
48V DC CAN BE LETHAL UNDER CERTAIN CONDITIONS

- 48V DC can cause electrical shock and serious injury
- Risk increases with wet conditions or broken skin
- Can cause burns, muscle contractions, and cardiac effects
- Always disconnect power before handling circuits
- Use insulated tools when working with live circuits
- Never work on circuits while powered
- Ensure all connections are properly insulated
- Keep work area dry

DISCLAIMER:
The author(s) of this project DISCLAIM ALL RESPONSIBILITY and LIABILITY
for any injury, death, property damage, or other consequences resulting
from the construction, modification, or use of this system.

By building or using this project, you acknowledge that:
- You understand the risks involved with high voltage systems
- You have the necessary skills and knowledge to work safely
- You accept full responsibility for your safety and others
- You will comply with all local electrical codes and regulations
- You use this information entirely at your own risk

IF YOU ARE NOT QUALIFIED TO WORK WITH HIGH VOLTAGE SYSTEMS,
DO NOT ATTEMPT TO BUILD THIS PROJECT.

Consult a qualified electrician or engineer if you have any doubts
about electrical safety or proper construction techniques.
=============================================================================

RECOMMENDED SAFETY PRACTICES:

1. ALWAYS disconnect power before touching any part of the circuit
2. Use a multimeter to verify circuits are de-energized
3. Wait for capacitors to discharge before handling
4. Implement emergency stop switch (easily accessible)
5. Use proper enclosure to prevent accidental contact
6. Label all high voltage sections clearly
7. Use appropriate personal protective equipment (PPE)
8. Never bypass safety interlocks or fuses
9. Keep flammable materials away from electrical components
10. Have fire extinguisher suitable for electrical fires nearby

COMPONENT RATINGS:
- Verify current ratings exceed maximum load
- Use fuses or circuit breakers for overcurrent protection
- Select wire gauge appropriate for current and voltage
- Use connectors and terminals rated for the application

TESTING PROCEDURE:
1. Inspect all connections before applying power
2. Test 5V section first (Arduino and logic circuits)
3. With 48V disconnected, verify relay operation (clicking sound)
4. Connect 48V with load disconnected
5. Measure voltages at all test points
6. Connect load only after verifying all safety checks
7. Monitor system during initial operation

LOCAL REGULATIONS:
- Check local electrical codes and regulations
- Some jurisdictions may require certified installation
- Building permits may be required
- Industrial safety standards may apply (OSHA, IEC, etc.)
- Comply with all applicable laws and standards

=============================================================================
HARDWARE REQUIREMENTS
=============================================================================

Components:
- Arduino Uno (or compatible)
- LCD2004 Display (20x4 with I2C module, address 0x27)
- MCP23017 I2C expander (address 0x20)
- 3x4 Matrix Keypad
- 3 Relays (for mechanical memory actuation)
- 2 Position Switches (CCW limit and read head sensor)
- Mechanical memory disk and head assembly

Pin Configuration:

ARDUINO:
  Digital Pin 9  → Read Head Switch
  Digital Pin 10 → Relay 1 (Write bit 1 mechanism)
  Digital Pin 11 → Relay 2 (Head rotation control)
  Digital Pin 12 → Relay 3 (Disk rotation control)
  Arduino UNO
    Analog Pin A4  → I2C SDA (LCD + MCP23017)
    Analog Pin A5  → I2C SCL (LCD + MCP23017)
  Arduino MEGA 2560
    Digital Pin 20  → I2C SDA (LCD + MCP23017)
    Digital Pin 21  → I2C SCL (LCD + MCP23017)
  Arduino M0
    Dedicated Pin

I2C DEVICES:
  LCD2004:   Address 0x27, connected to SDA/SCL
  MCP23017:  Address 0x20, connected to SDA/SCL

3X4 KEYPAD → MCP23017:
  Physical Pin 1 → PA0 (Column 2: keys 2, 5, 8, 0)
  Physical Pin 2 → PA1 (Row 1: keys 1, 2, 3)
  Physical Pin 3 → PA2 (Column 1: keys 1, 4, 7, *)
  Physical Pin 4 → PA3 (Row 4: keys *, 0, #)
  Physical Pin 5 → PA4 (Column 3: keys 3, 6, 9, #)
  Physical Pin 6 → PA5 (Row 3: keys 7, 8, 9)
  Physical Pin 7 → PA6 (Row 2: keys 4, 5, 6)

KEYPAD MATRIX:
       C1(PA2)  C2(PA0)  C3(PA4)
R1(PA1)   1        2        3
R2(PA6)   4        5        6
R3(PA5)   7        8        9
R4(PA3)   *        0        #

NOTE: The keypad pin mapping was determined through physical testing with
      a multimeter in continuity mode. Your keypad may have different wiring.

=============================================================================
SOFTWARE REQUIREMENTS
=============================================================================

Arduino Libraries (install via Library Manager):
- Wire.h (built-in)
- LiquidCrystal_I2C by Frank de Brabander
- Adafruit MCP23XXX by Adafruit (includes MCP23017 support)

Arduino IDE: 1.8.x or 2.x

Installation Steps:
1. Open Arduino IDE
2. Go to Sketch → Include Library → Manage Libraries
3. Search for "LiquidCrystal I2C" and install (by Frank de Brabander)
4. Search for "Adafruit MCP23XXX" and install (by Adafruit)
5. Wire.h is included automatically (built-in library)

=============================================================================
HOW IT WORKS
=============================================================================

NUMBER ENCODING (BCD - Binary-Coded Decimal)
Each decimal digit (0-9) is converted to 4 bits:
  0 → 0000    5 → 0101
  1 → 0001    6 → 0110
  2 → 0010    7 → 0111
  3 → 0011    8 → 1000
  4 → 0100    9 → 1001

Example: User enters "102"
  1 → 0001
  0 → 0000
  2 → 0010
  Result stored in memory: 000100000010 (12 bits total)

KEYPAD SCANNING MECHANISM:
The system uses matrix scanning to detect keypresses:
1. Each row is activated (set LOW) one at a time
2. All columns are read simultaneously
3. If a column reads LOW while a row is active, that key is pressed
4. Key position is determined by row-column intersection
5. Debouncing prevents multiple triggers from single press

WRITE PROCESS:
1. System auto-initializes and positions head at CCW (counter-clockwise) block
2. User presses numeric keys (0-9) on keypad
3. LCD displays "Input Sequence" with digits as they are entered
4. Each digit is IMMEDIATELY converted to 4 bits and written to memory
   - Press "1" → converts to 0001 → writes 4 bits → done
   - Press "0" → converts to 0000 → writes 4 bits → done
   - Press "2" → converts to 0010 → writes 4 bits → done
5. Display shows progress: "X/15" (current digit / maximum)
6. Maximum 15 digits can be entered (60 bits total)
7. User can press * at any time to reset and start over

READ PROCESS:
1. User presses # key to initiate read
2. System performs finalization moves:
   - Extra disk rotation to complete last write
   - Head moves back one position for alignment
3. LCD displays "Read Data" with "-> " prompt
4. System reads bits from memory sequentially
5. Every 4 bits are decoded to a decimal digit
6. Decoded digit appears on LCD IMMEDIATELY (real-time display)
7. Digits fill the display left-to-right, line by line
8. Display shows "Done" when read completes
9. System returns to input mode

REAL-TIME DECODE DISPLAY:
The read operation displays decoded numbers as they are read:
  Line 0: "     Read Data"
  Line 2: "-> 0123456789012"  (digits appear one by one)
  Line 3: "                Done"

Maximum 17 digits can be displayed on line 2 (20 chars - "-> " = 17)
If more digits exist, they wrap to line 3.

RESET FUNCTION (* key):
1. Displays "Reset System" message
2. Repositions head to CCW block (same as startup)
3. Clears all entered digits
4. Resets digit counter
5. Displays welcome screen
6. Returns to input mode

MECHANICAL SYNCHRONIZATION:
After the last digit is entered and before reading:
  activateRele(rele_3, sleep_time_rotate);  // Extra disk rotation
  activateRele(rele_2, sleep_time_read);    // Head back one position
This compensates for positioning offset during write operations and
ensures the read head is aligned properly with the first stored bit.

=============================================================================
USAGE INSTRUCTIONS
=============================================================================

STEP 1: Power Up & Initialization
- Connect Arduino to power
- LCD displays "System starting..."
- System automatically positions head to CCW block
- LCD shows "Reset System" during positioning
- LCD displays "Siemens Memory Ready" when complete
- After 3 seconds, shows:
    Line 0: "   Input Sequence"
    Line 2: "Enter digits 0-9"
    Line 3: " *->Reset    #->Read"
- System is now ready for input

STEP 2: Enter Numbers (Keys 0-9)
- Press any digit key (0-9) on keypad
- LCD updates to show:
    Line 0: "   Input Sequence"
    Line 1: "-> [your digits]"
    Line 3: "Writing Memory..."
- Digit is immediately written to memory (4 bits)
- Progress indicator appears: "X/15"
- Continue entering digits (maximum 15)
- Each digit is written immediately - no need to press "enter"

Example sequence for entering "1234":
  Press 1 → LCD shows "-> 1" → writes 0001 to memory → shows "1/15"
  Press 2 → LCD shows "-> 12" → writes 0010 to memory → shows "2/15"
  Press 3 → LCD shows "-> 123" → writes 0011 to memory → shows "3/15"
  Press 4 → LCD shows "-> 1234" → writes 0100 to memory → shows "4/15"

STEP 3: Reset System (Key *)
- Press * at any time to reset
- LCD displays "Reset System"
- Head returns to CCW position
- All entered digits are cleared
- System returns to input mode
- Use this to start over with a new number

STEP 4: Read Data (Key #)
- After entering digits, press # to read
- LCD clears and shows "Read Data"
- System performs alignment moves (disk forward, head back)
- Digits appear one by one on Line 2: "-> 0123456789"
- Each group of 4 bits is decoded and displayed immediately
- Watch the digits appear in real-time as memory is read
- After read completes, "Done" appears on Line 3
- Display shows result for 5 seconds
- System automatically returns to input mode for next sequence

STEP 5: Decode Output (Automatic)
The system automatically decodes 4-bit sequences to decimal:
  Memory: 0001 0000 0010
  Display: "-> 102"
No manual decoding needed - digits appear correctly on LCD.

=============================================================================
LCD DISPLAY MESSAGES
=============================================================================

Startup & Initialization:
"System starting..."       - Arduino boot sequence
"Reset System"             - Positioning head to start
"Siemens Memory Ready"     - System initialized (sliding text effect)
"Enter digits 0-9"         - Instructions
" *->Reset    #->Read"     - Key functions

Input Mode:
"   Input Sequence"        - Main header during input
"-> [digits]"              - Shows entered digits (line 1)
"Writing Memory..."        - Brief status during write
"X/15"                     - Progress indicator (X = current, 15 = max)
"Max digits reached!"      - Cannot enter more than 15 digits

Reset Operation:
"Reset System"             - System is resetting
(then returns to startup sequence)

Read Operation:
"     Read Data"           - Read operation header
"-> [decoded digits]"      - Decoded numbers appear here
"                Done"     - Read operation complete

Error Messages:
"No data available!"       - Attempted read with disk at end position
"No data to read!"         - Pressed # without entering any digits
"MCP23017 ERROR!"          - MCP23017 not detected (halts execution)

=============================================================================
CONFIGURATION PARAMETERS
=============================================================================

Timing Constants (in milliseconds):
  sleep_time_rotate = 100;  // Disk rotation timing
  sleep_time_write = 100;   // Write operation timing
  sleep_time_read = 100;    // Read operation timing
  delay_small = 200;        // Text display sliding effect
  delay_medium = 2000;      // Status message duration
  delay_long = 3000;        // Important message duration
  delay_huge = 5000;        // Final result display duration

Tuning the Timing Constants:
- sleep_time_* values control mechanical relay actuation
  - Increase if bits are unreliable or mechanisms are slow
  - Decrease for faster operation (after confirming reliability)
  - Typical range: 50-200ms depending on hardware
- delay_* values control LCD message display duration
  - Adjust for preferred user interface speed
  - delay_small affects sliding text speed (character-by-character)
  - delay_huge affects how long final results are shown

Memory Configuration:
  const int max_numbers = 15;  // Maximum digits (15 × 4 = 60 bits)

I2C Addresses:
  LCD2004:  0x27 (or 0x3F for some modules)
  MCP23017: 0x20 (default, configurable with A0/A1/A2 pins)
Note: use the sketch "Utility_01_LCD_address.ino" to detect the correct addresses if needed

To change LCD address (if 0x27 doesn't work):
  LiquidCrystal_I2C lcd(0x3F, 20, 4);

To change MCP23017 address:
  if (!mcp.begin_I2C(0x21)) {  // Change 0x20 to desired address

Keypad Pin Mapping:
  byte rowPins[ROWS] = {1, 6, 5, 3};  // PA1, PA6, PA5, PA3
  byte colPins[COLS] = {2, 0, 4};     // PA2, PA0, PA4

NOTE: These pin assignments are based on physical testing of a specific
      keypad. Different keypad models may have different internal wiring.
      Use a multimeter to verify your keypad's pin configuration.

=============================================================================
TECHNICAL DETAILS
=============================================================================

BINARY CONVERSION ALGORITHM:
The digitToBits() function extracts 4 bits using bitwise operations:
  bits[0] = (num >> 3) & 1;  // Bit 3 (MSB) - weight 8
  bits[1] = (num >> 2) & 1;  // Bit 2 - weight 4
  bits[2] = (num >> 1) & 1;  // Bit 1 - weight 2
  bits[3] = num & 1;         // Bit 0 (LSB) - weight 1

Example for digit 5 (binary 0101):
  5 >> 3 = 0, masked = 0  →  bits[0] = 0
  5 >> 2 = 1, masked = 1  →  bits[1] = 1
  5 >> 1 = 2, masked = 0  →  bits[2] = 0
  5 >> 0 = 5, masked = 1  →  bits[3] = 1
Result: [0, 1, 0, 1] which is 0101 in binary = 5 in decimal

DECODE ALGORITHM (Read Operation):
The readAndDecodeMemory() function converts 4 bits back to decimal:
  for (int j = 0; j < 4; j++) {
    if (fourBits.charAt(j) == '1') {
      decimalValue += (1 << (3 - j));
    }
  }

Example decoding "0101":
  j=0: '0' → skip
  j=1: '1' → add (1 << 2) = 4 → decimalValue = 4
  j=2: '0' → skip
  j=3: '1' → add (1 << 0) = 1 → decimalValue = 5
Result: 5

KEYPAD MATRIX SCANNING:
The scanKeypad() function implements standard matrix scanning:
1. Set all rows HIGH (inactive)
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

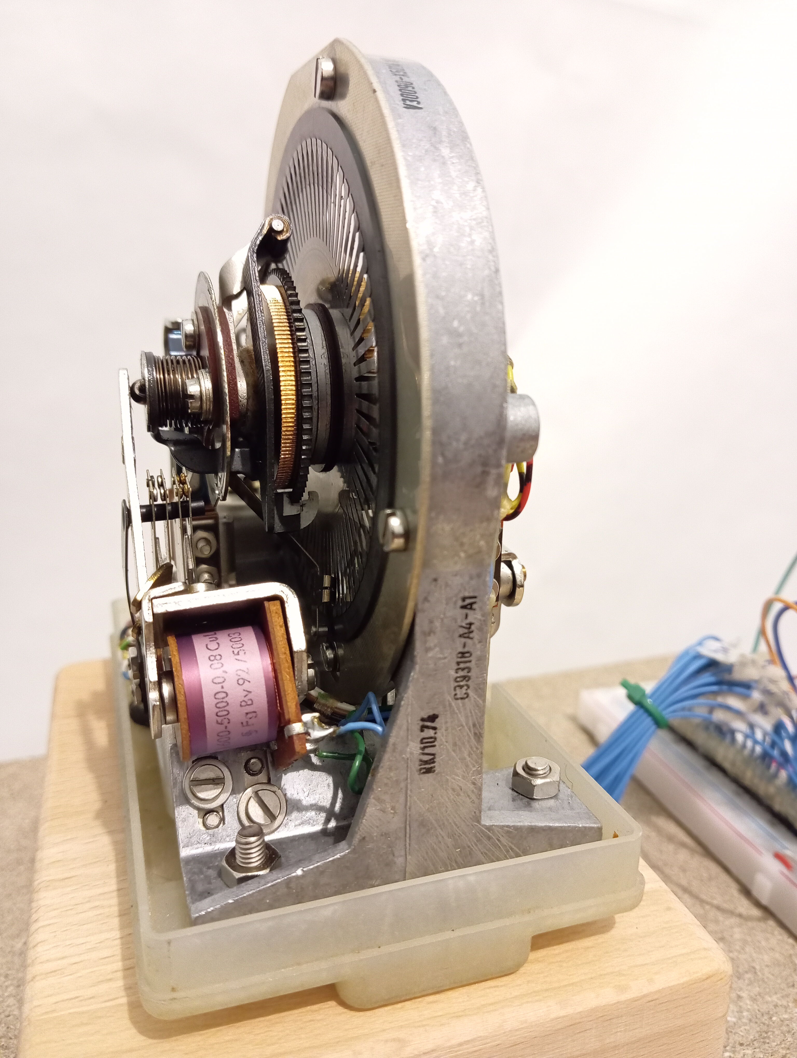
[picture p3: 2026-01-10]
photos/Rele_2-MultiSwitch_2_a.jpg

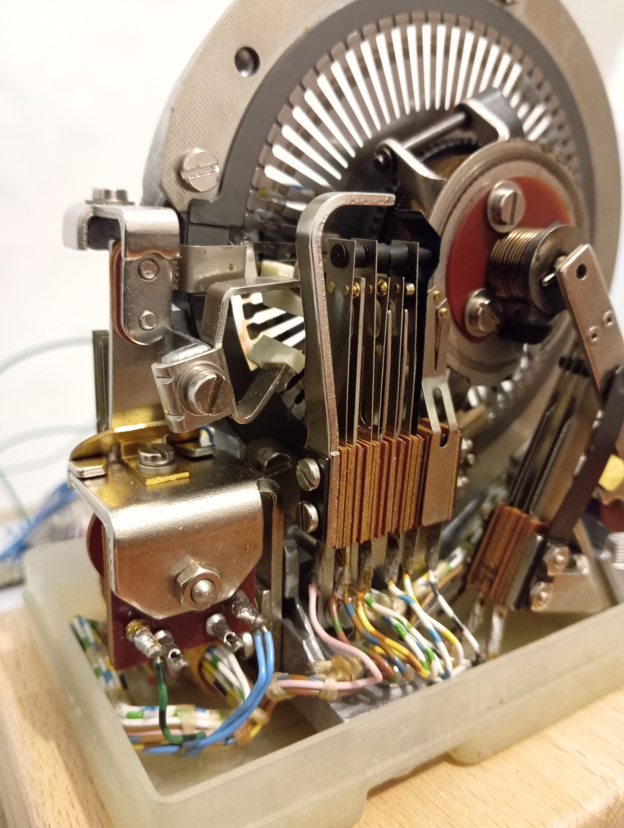
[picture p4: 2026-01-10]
photos/Rele_1-MultiSwitch_1_b.jpg

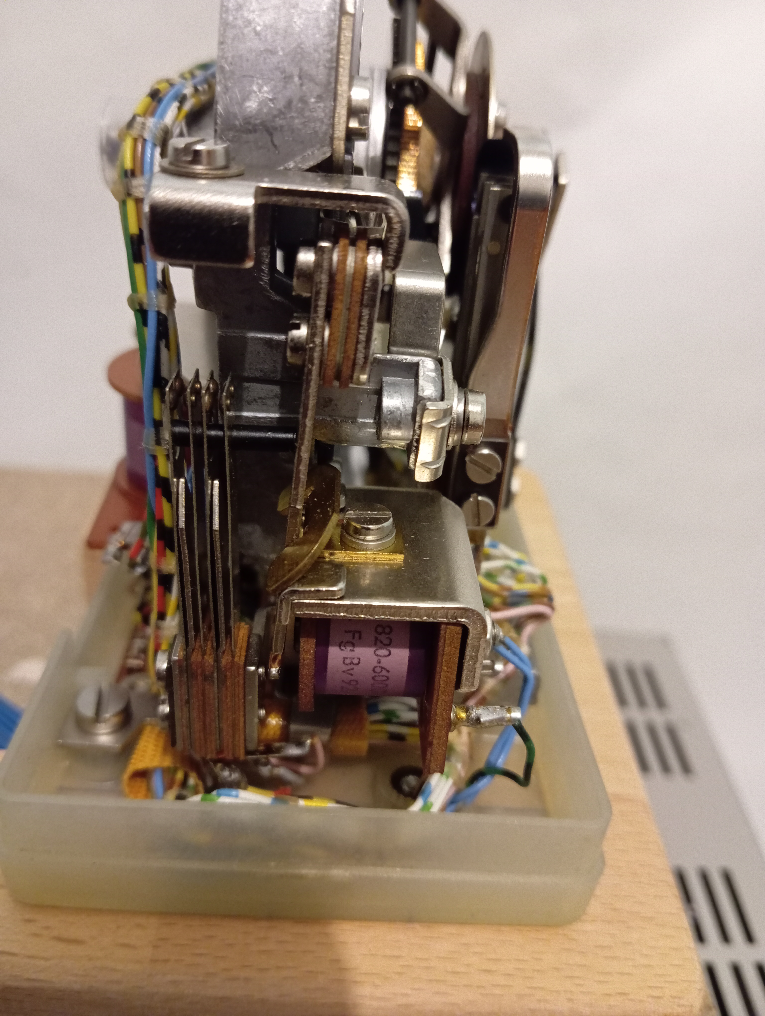
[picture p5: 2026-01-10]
photos/Rele_1-MultiSwitch_4.jpg

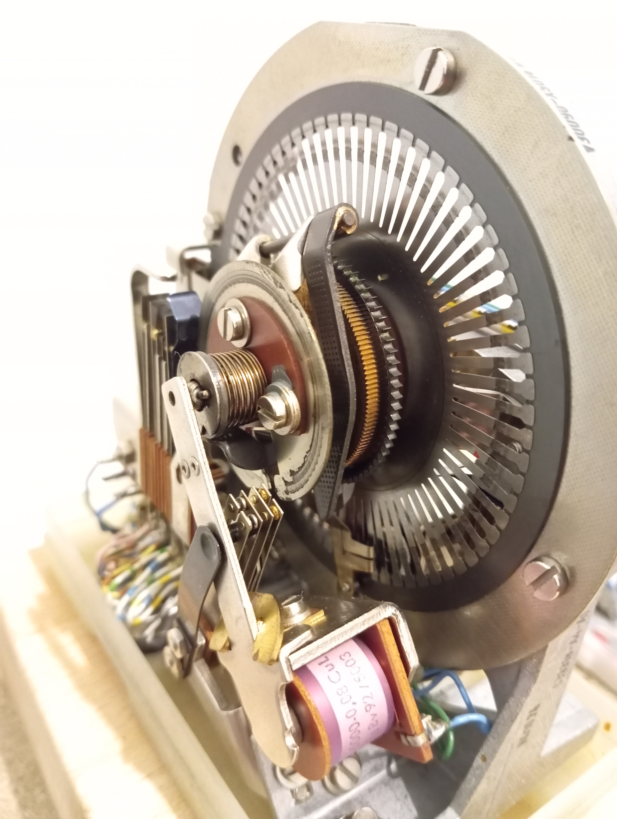
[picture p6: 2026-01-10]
photos/Rele_2-MultiSwitch_2_b.jpg

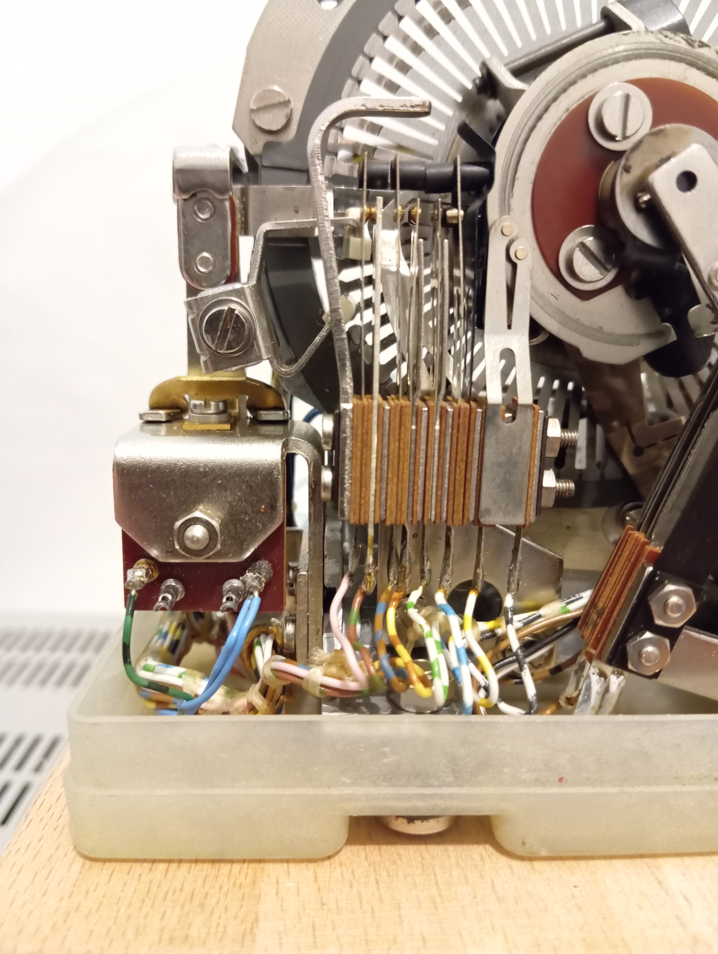
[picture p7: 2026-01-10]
photos/Rele_1-MultiSwitch_1_a.jpg

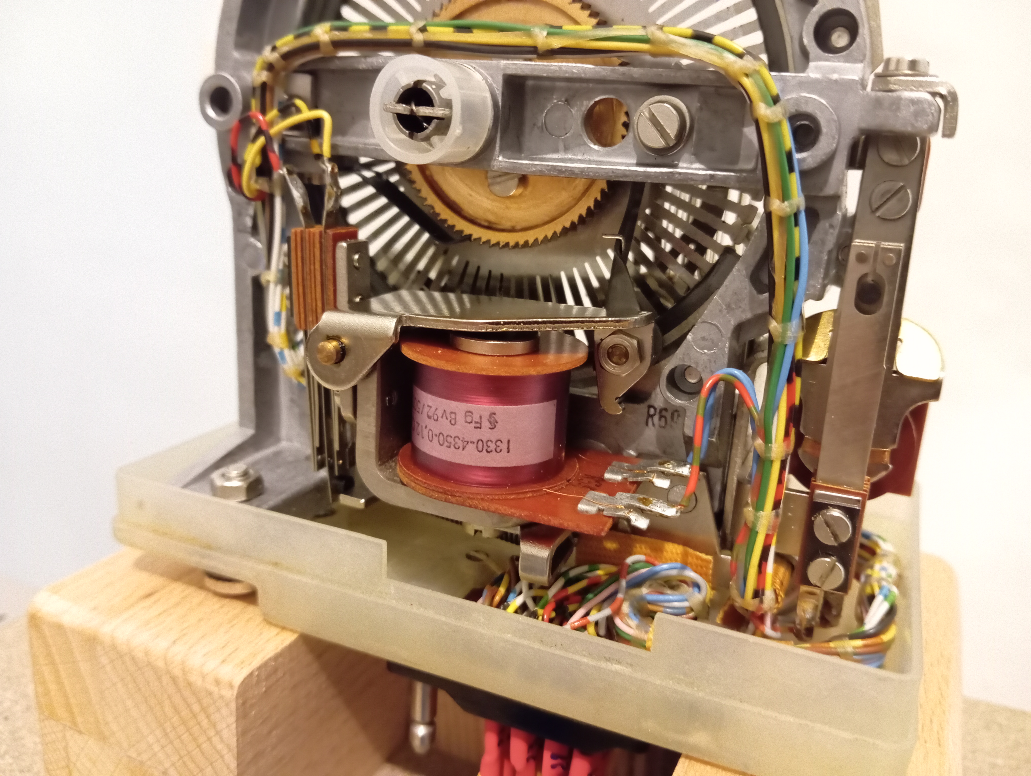
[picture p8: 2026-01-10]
photos/Rele_3-MultiSwitch_3_4_a.jpg

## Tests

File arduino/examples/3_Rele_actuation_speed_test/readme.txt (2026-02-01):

Test for the rele speed actuation

**File:** `Rele_actuation_speed_test.ino`

**Purpose:** This sketch is designed to test the actuation speed of the mechanical memory system. It provides functionality to position the disk and head, and write individual bits to the memory.

**Hardware Requirements:**
- 3 push buttons (pins 3, 4, 5)
- 3 switches for position feedback (pins 6, 7, 8)
- 3 relays for mechanical actuation (pins 10, 11, 12)
- OLED display (128x64, I2C address 0x3C)

**Functionality:**
- **Button 1:** Initiates setup procedure - moves the disk and head to the CCW (counter-clockwise) block position. The system uses Switch C to detect when the initial position is reached. If already at the end position, it moves forward twice then returns to ensure proper positioning.
- **Button 2:** Writes a bit value of 1 to the memory. Activates Relay 1, then pulses Relay 3 to write the bit, then deactivates Relay 1.
- **Button 3:** Writes a bit value of 0 to the memory. Pulses Relay 3 to write the bit.

**Display Feedback:**
- Shows "Initial SetUp..." when Button 1 is pressed
- Shows "Write bit -> 1" when Button 2 is pressed
- Shows "Write bit -> 0" when Button 3 is pressed

**Timing Parameters:**
- Relay actuation time: 100ms
- Disk movement delay: 100ms

## Pin Mapping

| Component | Pin Number |
|---|---|
| Button 1  | 3 |
| Button 2  | 4 |
| Button 3  | 5 |
| Switch A  | 6 |
| Switch B  | 7 |
| Switch C  | 8 |
| Relay 1 | 10 |
| Relay 2 | 11 |
| Relay 3 | 12 |

## Libraries Required
- Wire.h (built-in)
- Adafruit_GFX.h
- Adafruit_SSD1306.h

## Notes

- All sketches initialize relays to the OFF state (LOW) on startup
- Serial communication is initialized at 9600 baud for debugging purposes
- Small delays (1ms) are implemented between pin reads for stability
- OLED display address is set to 0x3C (default for most SSD1306 displays)

=============================================================================
POWER SUPPLY AND SAFETY WARNING
=============================================================================

CRITICAL SAFETY INFORMATION - READ BEFORE BUILDING

This system requires TWO separate power supplies:

1. LOW VOLTAGE SECTION (5V DC):
   - Arduino board
   - LCD2004 display
   - MCP23017 I2C expander
   - Digital signal lines
   - Control circuitry

2. HIGH VOLTAGE SECTION (48V DC):
   - Relay coils
   - Mechanical memory actuation system
   - Motor drives

ELECTRICAL ISOLATION:
The 5V and 48V sections MUST be electrically isolated:
- Relays provide optical or magnetic isolation between sections
- Arduino controls relay coils (low voltage side)
- Relay contacts switch high voltage power
- NEVER connect 48V directly to Arduino pins
- Use optocouplers or relay modules with built-in isolation

WIRING REQUIREMENTS:
- Use appropriate wire gauge for 48V current levels
- Ensure proper insulation on all 48V connections
- Keep 48V wiring separate from 5V signal wiring
- Use terminal blocks or connectors rated for 48V
- Implement proper grounding for safety

** DANGER - HIGH VOLTAGE WARNING **
=============================================================================
48V DC CAN BE LETHAL UNDER CERTAIN CONDITIONS

- 48V DC can cause electrical shock and serious injury
- Risk increases with wet conditions or broken skin
- Can cause burns, muscle contractions, and cardiac effects
- Always disconnect power before handling circuits
- Use insulated tools when working with live circuits
- Never work on circuits while powered
- Ensure all connections are properly insulated
- Keep work area dry

DISCLAIMER:
The author(s) of this project DISCLAIM ALL RESPONSIBILITY and LIABILITY
for any injury, death, property damage, or other consequences resulting
from the construction, modification, or use of this system.

By building or using this project, you acknowledge that:
- You understand the risks involved with high voltage systems
- You have the necessary skills and knowledge to work safely
- You accept full responsibility for your safety and others
- You will comply with all local electrical codes and regulations
- You use this information entirely at your own risk

IF YOU ARE NOT QUALIFIED TO WORK WITH HIGH VOLTAGE SYSTEMS,
DO NOT ATTEMPT TO BUILD THIS PROJECT.

Consult a qualified electrician or engineer if you have any doubts
about electrical safety or proper construction techniques.
=============================================================================

RECOMMENDED SAFETY PRACTICES:

1. ALWAYS disconnect power before touching any part of the circuit
2. Use a multimeter to verify circuits are de-energized
3. Wait for capacitors to discharge before handling
4. Implement emergency stop switch (easily accessible)
5. Use proper enclosure to prevent accidental contact
6. Label all high voltage sections clearly
7. Use appropriate personal protective equipment (PPE)
8. Never bypass safety interlocks or fuses
9. Keep flammable materials away from electrical components
10. Have fire extinguisher suitable for electrical fires nearby

COMPONENT RATINGS:
- Verify current ratings exceed maximum load
- Use fuses or circuit breakers for overcurrent protection
- Select wire gauge appropriate for current and voltage
- Use connectors and terminals rated for the application

TESTING PROCEDURE:
1. Inspect all connections before applying power
2. Test 5V section first (Arduino and logic circuits)
3. With 48V disconnected, verify relay operation (clicking sound)
4. Connect 48V with load disconnected
5. Measure voltages at all test points
6. Connect load only after verifying all safety checks
7. Monitor system during initial operation

LOCAL REGULATIONS:
- Check local electrical codes and regulations
- Some jurisdictions may require certified installation
- Building permits may be required
- Industrial safety standards may apply (OSHA, IEC, etc.)
- Comply with all applicable laws and standards

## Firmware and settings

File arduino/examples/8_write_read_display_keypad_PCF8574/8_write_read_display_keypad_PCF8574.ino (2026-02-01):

#include <Wire.h>
#include <LiquidCrystal_I2C.h>
#include <PCF8574.h>

/*
48V POWER SUPPLY

IMPORTANT: for safety reason read the related readme.txt file

DISCLAIMER:
The author(s) of this project DISCLAIM ALL RESPONSIBILITY and LIABILITY
for any injury, death, property damage, or other consequences resulting
from the construction, modification, or use of this system.

By building or using this project, you acknowledge that:
- You understand the risks involved with high voltage systems
- You have the necessary skills and knowledge to work safely
- You accept full responsibility for your safety and others
- You will comply with all local electrical codes and regulations
- You use this information entirely at your own risk

IF YOU ARE NOT QUALIFIED TO WORK WITH HIGH VOLTAGE SYSTEMS,
DO NOT ATTEMPT TO BUILD THIS PROJECT.
*/

/*
MECHANICAL MEMORY SYSTEM WITH KEYPAD INPUT
===========================================

This sketch implements a complete mechanical memory system with 3x4 matrix keypad input.
Numbers (0-9) are converted to 4-bit BCD sequences and stored mechanically on a rotating disk.
The system uses a PCF8574 I2C expander to handle the keypad matrix.

REQUIRED LIBRARIES (install via Library Manager):
- Wire.h (built-in)
- LiquidCrystal_I2C by Frank de Brabander
- PCF8574 library by Rob Tillaart

HARDWARE:
- Arduino Uno
- LCD2004 (20x4 with I2C module, address 0x27)
- PCF8574 I2C expander (address 0x20)
- 3x4 Matrix Keypad connected to PCF8574 (P0-P6)
- 3 Relays on Arduino pins 10, 11, 12
- Position switch on Arduino pin 8 (CCW limit sensor)
- Read head switch on Arduino pin 9
- Mechanical memory disk and head assembly

KEYPAD LAYOUT:
  1  2  3
  4  5  6
  7  8  9
  *  0  #

KEYPAD PIN MAPPING (tested configuration):
// Pin out inverted for montability reasons
Physical Pin → PCF8574 Pin → Function
Pin 1        → P6          → Column 2 (2, 5, 8, 0)
Pin 2        → P5          → Row 1 (1, 2, 3)
Pin 3        → P4          → Column 1 (1, 4, 7, *)
Pin 4        → P3          → Row 4 (*, 0, #)
Pin 5        → P2          → Column 3 (3, 6, 9, #)
Pin 6        → P1          → Row 3 (7, 8, 9)
Pin 7        → P0          → Row 2 (4, 5, 6)

FUNCTIONS:
- Keys 0-9: Input numbers (max 15 digits), each digit is immediately written to memory
- Key *: Reset system (reposition head to CCW block, clear sequence)
- Key #: Read data from memory and display decoded decimal numbers in real-time

OPERATION:
1. System initializes and auto-resets head to CCW position
2. User enters digits 0-9, each is immediately converted to 4 bits and written
3. LCD shows "Input Sequence" with entered digits
4. Press * to reset system and clear sequence
5. Press # to read memory and display decoded digits in real-time
*/

// Output relay pins (on Arduino)
const int rele_1 = 10; // Relay 1: Write bit 1 mechanism
const int rele_2 = 11; // Relay 2: Head rotation control
const int rele_3 = 12; // Relay 3: Disk rotation control

// Input switches (on Arduino)
const int switch_A = 6; // Switch A (reserved for future use)
const int switch_B = 7; // Switch B (reserved for future use)
const int switch_C = 8; // Switch C: CCW (counter-clockwise) limit sensor
const int switch_read = 9; // Switch: Reading head position sensor

// Timing constants (milliseconds)
const int sleep_time_rotate = 100; // Relay actuation time during rotation
const int sleep_time_write = 100;  // Relay actuation time during write operation
const int sleep_time_read = 100;   // Relay actuation time during read operation
const int delay_small = 200;       // Small delay for text display (sliding effect)
const int delay_medium = 2000;     // Medium delay for status messages
const int delay_long = 3000;       // Long delay for important messages
const int delay_huge = 5000;       // Extended delay for final results

// Memory configuration
const int max_numbers = 15; // Maximum number of digits that can be stored

// Global variables
String inputSequence = ""; // Stores user input digits (decimal format)
String bitSequence = "";   // Stores read bit sequence (binary format)
int digitCount = 0;        // Counter for entered digits

// LCD2004 display configuration (20 characters x 4 lines, I2C address 0x27)
LiquidCrystal_I2C lcd(0x27, 20, 4);

// PCF8574 I2C expander (I2C address 0x20)
PCF8574 pcf(0x20);

// Keypad matrix configuration
const byte ROWS = 4; // Four rows
const byte COLS = 3; // Three columns

// Keypad key mapping
char keys[ROWS][COLS] = {
  {'1', '2', '3'},
  {'4', '5', '6'},
  {'7', '8', '9'},
  {'*', '0', '#'}
};

// Pin out inverted for montability reasons
// PCF8574 pin assignments (based on physical testing)
// Rows control which horizontal line is active
byte rowPins[ROWS] = {5, 0, 1, 3}; // P5, P0, P1, P3
// Columns detect which vertical line is pressed
byte colPins[COLS] = {4, 6, 2};    // P4, P6, P2

// ************************* KEYPAD FUNCTIONS *************************

// FUNCTION -> Scan keypad matrix and return pressed key (or 0 if none)
char scanKeypad() {
  // Scan each row
  for (int r = 0; r < ROWS; r++) {
    // Prepare byte with current row LOW, others HIGH
    byte rowPattern = 0xFF; // All HIGH initially
    bitClear(rowPattern, rowPins[r]); // Set current row LOW
    
    // Write pattern to PCF8574
    pcf.write8(rowPattern);
    delay(5); // Small delay for signal stability
    
    // Read all pins from PCF8574
    byte readValue = pcf.read8();
    
    // Check each column
    for (int c = 0; c < COLS; c++) {
      if (bitRead(readValue, colPins[c]) == LOW) {
        // Key pressed! Wait for release to avoid multiple triggers
        while (bitRead(pcf.read8(), colPins[c]) == LOW) {
          delay(10);
        }
        delay(50); // Debounce delay
        return keys[r][c];
      }
    }
  }
  
  return 0; // No key pressed
}

// ************************* MEMORY FUNCTIONS *************************

// FUNCTION -> Activate/deactivate a relay with specified timing
void activateRele(int pin_rele, int sleepping) {
  digitalWrite(pin_rele, HIGH);
  delay(sleepping);
  digitalWrite(pin_rele, LOW);
  delay(sleepping);
}

// FUNCTION -> Convert a decimal digit (0-9) to a 4-bit binary array
void digitToBits(char digit, int bits[4]) {
  int num = digit - '0'; // Convert char to int (e.g., '5' -> 5)
  
  // Extract the 4 bits using bitwise operations (MSB to LSB)
  bits[0] = (num >> 3) & 1; // Bit 3 (Most Significant Bit)
  bits[1] = (num >> 2) & 1; // Bit 2
  bits[2] = (num >> 1) & 1; // Bit 1
  bits[3] = num & 1;        // Bit 0 (Least Significant Bit)
}

// FUNCTION -> Write a single bit to mechanical memory
void writeSingleBit(int bit_value) {
  if (bit_value == 1) {
    // Write bit 1: activate write mechanism, then rotate disk
    digitalWrite(rele_1, HIGH);
    delay(sleep_time_write);
    activateRele(rele_3, sleep_time_write);
    digitalWrite(rele_1, LOW);
  } else {
    // Write bit 0: only rotate disk (no write mechanism)
    activateRele(rele_3, sleep_time_rotate);
  }
}

// FUNCTION -> Write a single digit to memory (converts to 4 bits and writes sequentially)
void writeDigitToMemory(char digit) {
  int bits[4];
  digitToBits(digit, bits);
  
  // Write each of the 4 bits to memory
  for (int j = 0; j < 4; j++) {
    writeSingleBit(bits[j]);
    delay(10); // Small delay between bits for mechanical stability
  }
}

// ************************* DISPLAY FUNCTIONS *************************

// FUNCTION -> Display text character by character with delay (sliding effect)
void printSlow(const char* text, unsigned long delayMs) {
  while (*text) {
    lcd.print(*text);
    delay(delayMs);
    text++;
  }
}

// ************************* SYSTEM FUNCTIONS *************************

// FUNCTION -> Reset system: clear sequence and reposition head to CCW block
void resetSystem() {
  lcd.clear();
  lcd.setCursor(0, 0);
  lcd.print("    Reset System");
  delay(delay_medium);
  
  // Check current position of CCW limit switch
  int switchState_C = digitalRead(switch_C);
  delay(1); // Delay for reading stability
  
  if (switchState_C == LOW) {
    // If disk is already at the end position, move forward 2 steps then return
    // This ensures proper positioning at block+1
    activateRele(rele_3, sleep_time_rotate);
    activateRele(rele_3, sleep_time_rotate);
    switchState_C = digitalRead(switch_C);
  }
  
  // Rotate head counter-clockwise until CCW limit switch is triggered
  while (switchState_C == HIGH) {
    activateRele(rele_2, sleep_time_rotate);
    switchState_C = digitalRead(switch_C);
    delay(1); // Delay for reading stability
  }
  
  // Clear all sequence data
  inputSequence = "";
  digitCount = 0;
  
  // Display ready message
  lcd.clear();
  lcd.setCursor(0, 0);
  printSlow("Siemens Memory Ready", delay_small);
  lcd.setCursor(0, 2);
  lcd.print("Enter digits 0-9");
  lcd.setCursor(0, 3);
  lcd.print(" *->Reset    #->Read");
  delay(delay_long);
  
  // Display input prompt
  lcd.clear();
  lcd.setCursor(0, 0);
  lcd.print("   Input Sequence");
}

// FUNCTION -> Read memory and decode to decimal digits in real-time
void readAndDecodeMemory() {
  // Check if disk is at valid starting position
  int switchState_C = digitalRead(switch_C);
  delay(1); // Delay for reading stability

  if (switchState_C == LOW) {
    // Disk is at end position, cannot read
    lcd.clear();
    lcd.setCursor(0, 0);
    lcd.print("No data available!");
    delay(delay_long);
    return;
  }

  // Display read header
  lcd.clear();
  lcd.setCursor(0, 0);
  lcd.print("     Read Data ");
  lcd.setCursor(0, 2);
  lcd.print("-> ");
  
  String fourBits = "";  // Buffer to accumulate 4 bits
  int cursorPos = 3;     // Current LCD cursor position (starting after "-> ")
  int lineNumber = 2;    // Current line (starting at line 2)

  // Read bits from memory until CCW limit is reached
  while (switchState_C == HIGH) {
    // Read current bit from head switch
    int switchState_read = digitalRead(switch_read);
    delay(1); // Delay for reading stability

    // Convert to bit character (inverted logic)
    char bit = (!switchState_read) ? '1' : '0';
    fourBits += bit;
    
    // When 4 bits are collected, decode to decimal digit
    if (fourBits.length() == 4) {
      // Convert 4-bit binary to decimal value
      int decimalValue = 0;
      for (int j = 0; j < 4; j++) {
        if (fourBits.charAt(j) == '1') {
          decimalValue += (1 << (3 - j)); // Bit weighting: 8, 4, 2, 1
        }
      }
      
      // Display decoded digit on LCD
      lcd.print(decimalValue);
      cursorPos++;
      delay(delay_small); // Small delay for visual effect
      
      // Move to next line if current line is full (20 chars)
      if (cursorPos >= 20) {
        lineNumber++;
        if (lineNumber < 4) { // Stay within LCD bounds
          lcd.setCursor(0, lineNumber);
          cursorPos = 0;
        }
      }
      
      fourBits = ""; // Clear buffer for next digit
    }
    
    // Rotate disk to next position
    activateRele(rele_2, sleep_time_read);
    switchState_C = digitalRead(switch_C);
    delay(1); // Delay for reading stability
  }
  
  // Display completion message
  lcd.setCursor(0, 3);
  lcd.print("                Done");
  delay(delay_huge);
  
  // Clear input sequence for next operation
  inputSequence = "";
  digitCount = 0;
  
  // Return to input mode
  lcd.clear();
  lcd.setCursor(0, 0);
  lcd.print("   Input Sequence");
}

// ************************* SETUP SECTION *************************
void setup() {
  // Initialize serial communication for debugging
  Serial.begin(9600);
  
  // Configure Arduino digital pins
  pinMode(switch_A, INPUT);
  pinMode(switch_B, INPUT);
  pinMode(switch_C, INPUT);
  pinMode(switch_read, INPUT);
  pinMode(rele_1, OUTPUT);
  pinMode(rele_2, OUTPUT);
  pinMode(rele_3, OUTPUT);
  
  // Initialize all relays to OFF state
  digitalWrite(rele_1, LOW);
  digitalWrite(rele_2, LOW);
  digitalWrite(rele_3, LOW);
  
  // Initialize LCD2004 display
  lcd.init();
  lcd.backlight();
  lcd.clear();
  lcd.setCursor(0, 0);
  lcd.print("System starting...");
  delay(delay_medium);
  
  // Initialize PCF8574 I2C expander
  if (!pcf.begin()) {
    Serial.println("ERROR: PCF8574 not found!");
    lcd.clear();
    lcd.setCursor(0, 0);
    lcd.print("PCF8574 ERROR!");
    while (1); // Halt execution if PCF8574 fails
  }
   
  // Configure PCF8574 pins for keypad matrix
  // All pins start as INPUT with pull-up (default for PCF8574)
  // Rows will be driven LOW one at a time during scanning
  // Columns will be read to detect key presses
  pcf.write8(0xFF); // Set all pins HIGH initially
  
  Serial.println("PCF8574 initialized");
  resetSystem();
}

// ************************* LOOP SECTION *************************
void loop() {
  // Scan keypad for user input
  char key = scanKeypad();
  
  if (key) { 
    // Handle numeric keys (0-9): input and write to memory
    if (key >= '0' && key <= '9') {
      if (digitCount < max_numbers) {
        // Add digit to input sequence
        inputSequence += key;
        digitCount++;
        
        // Update display to show current sequence
        lcd.clear();
        lcd.setCursor(0, 0);
        lcd.print("   Input Sequence");
        lcd.setCursor(0, 1);
        lcd.print("-> ");
        lcd.print(inputSequence);
        
        // Show writing status
        lcd.setCursor(0, 3);
        lcd.print("Writing Memory... ");
        
        // Write digit to memory immediately (4 bits)
        writeDigitToMemory(key);
        
        // Clear writing message and show progress
        lcd.setCursor(0, 3);
        lcd.print("              "); // Clear previous text
        lcd.print(digitCount);
        lcd.print("/");
        lcd.print(max_numbers);

      } else {
        // Maximum digit limit reached
        lcd.setCursor(0, 3);
        lcd.print("Max digits reached!");
        delay(delay_long);
        lcd.setCursor(0, 3);
        lcd.print("                    "); // Clear message
      }
    }
    
    // Handle * key: reset system
    else if (key == '*') {
      resetSystem();
    }
    
    // Handle # key: read and decode memory
    else if (key == '#') {
      if (digitCount > 0) {
        // Finalize write operation with compensation moves
        activateRele(rele_3, sleep_time_rotate); // Extra disk rotation
        activateRele(rele_2, sleep_time_read);   // Head moves back one position
        
        // Read memory and display decoded digits
        readAndDecodeMemory();
      } else {
        // No data has been entered yet
        lcd.clear();
        lcd.setCursor(0, 0);
        lcd.print("No data to read!");
        delay(delay_long);
        lcd.clear();
        lcd.setCursor(0, 0);
        lcd.print("   Input Sequence");
      }
      // Reset digit counter for next write operation
      digitCount = 0;
    }
  }
}

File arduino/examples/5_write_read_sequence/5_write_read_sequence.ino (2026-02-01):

#include <Wire.h>
#include <Adafruit_GFX.h>
#include <Adafruit_SSD1306.h>

/*
48V POWER SUPPLY

IMPORTANT: for safety reason read the related readme.txt file

DISCLAIMER:
The author(s) of this project DISCLAIM ALL RESPONSIBILITY and LIABILITY
for any injury, death, property damage, or other consequences resulting
from the construction, modification, or use of this system.

By building or using this project, you acknowledge that:
- You understand the risks involved with high voltage systems
- You have the necessary skills and knowledge to work safely
- You accept full responsibility for your safety and others
- You will comply with all local electrical codes and regulations
- You use this information entirely at your own risk

IF YOU ARE NOT QUALIFIED TO WORK WITH HIGH VOLTAGE SYSTEMS,
DO NOT ATTEMPT TO BUILD THIS PROJECT.
*/

/*
Program to test the write/read process
- The memory is automatically initialized to the starting position (CCW block)
- Button 1 press:
   The program reads a number sequence stored in an internal variable (myNumber)
    - Numbers from 0 to 9
    - Maximum 15 digits
   Each number is converted into a 4-bit sequence (from 0000 to 1001) that will be
   sequentially stored in memory
- After the write process, the user can read the sequence by pressing button 3
- Button 2 is not used
- A flag_write is implemented to prevent consecutive writes. If the flag is set to 0,
  the write operation is allowed, otherwise it's blocked
*/

// Input pins
const int button_1 = 3; // Button 1: write number sequence
const int button_2 = 4; // Button 2: not used
const int button_3 = 5; // Button 3: read stored data

// Input switches
const int switch_A = 6; // Switch A
const int switch_B = 7; // Switch B
const int switch_C = 8; // Switch C
const int switch_read = 9; // Switch reading head

// Output relay pins
const int rele_1 = 10; // Relay 1
const int rele_2 = 11; // Relay 2
const int rele_3 = 12; // Relay 3

// Timing constants
const int sleep_time_rotate = 100; // Relay actuation time during rotation (ms)
const int sleep_time_write = 100; // Relay actuation time during write operation (ms)
const int sleep_time_read = 100; // Relay actuation time during read operation (ms)

const int max_numbers = 15; // Maximum number of single digits to be stored

// Global flag to prevent multiple consecutive writes
int flag_write = 0; // 0 = write allowed, 1 = write blocked

// Number sequence to write
String myNumber = "0123456789012";

// OLED display configuration
#define SCREEN_WIDTH 128
#define SCREEN_HEIGHT 64
#define OLED_RESET -1
Adafruit_SSD1306 display(SCREEN_WIDTH, SCREEN_HEIGHT, &Wire, OLED_RESET);

// ************************* FUNCTIONS SECTION *************************

// FUNCTION -> Activate/deactivate a relay
void activateRele(int pin_rele, int sleepping) {
  digitalWrite(pin_rele, HIGH);
  delay(sleepping);
  digitalWrite(pin_rele, LOW);
  delay(sleepping);
}

// FUNCTION -> Display status messages on the OLED display
void display_option(int option) {
  display.clearDisplay();
  display.setTextSize(1);
  display.setTextColor(SSD1306_WHITE);
  display.setCursor(0, 0);
  
  if (option == 1) { display.println("Initial SetUp..."); }
  if (option == 2) { display.println("Writing sequence..."); }
  if (option == 3) { display.println("Write complete!"); }
  if (option == 4) { display.println("Reading data..."); }
  if (option == 5) { display.println("End of disk!"); }
  if (option == 6) { display.println("No data available!"); }
  if (option == 7) { 
    display.println("Write blocked!");
    display.println("Read first!");
  }
  
  display.display();
}

// FUNCTION -> Convert a digit (0-9) to a 4-bit array
void digitToBits(char digit, int bits[4]) {
  int num = digit - '0'; // Convert char to int (e.g., '5' -> 5)
  
  // Extract the 4 bits (from most significant to least significant)
  bits[0] = (num >> 3) & 1; // Bit 3 (MSB)
  bits[1] = (num >> 2) & 1; // Bit 2
  bits[2] = (num >> 1) & 1; // Bit 1
  bits[3] = num & 1;        // Bit 0 (LSB)
}

// FUNCTION -> Write a single bit to memory
void writeSingleBit(int bit_value) {
  if (bit_value == 1) {
    // Write bit 1
    digitalWrite(rele_1, HIGH);
    delay(sleep_time_write);
    activateRele(rele_3, sleep_time_write);
    digitalWrite(rele_1, LOW);
  } else {
    // Write bit 0
    activateRele(rele_3, sleep_time_rotate);
  }
}

// FUNCTION -> Write the entire number sequence to memory
void writeNumberSequence(String number) {
  int bits[4];
  
  display_option(2); // Show "Writing sequence..."
  
  for (int i = 0; i < number.length() && i < max_numbers; i++) {
    digitToBits(number[i], bits);
    // Write the 4 bits to memory
    for (int j = 0; j < 4; j++) {
      writeSingleBit(bits[j]);
      delay(10); // Small delay between bits
    } 
  }
  activateRele(rele_3, sleep_time_rotate); // Rotate the disk otherwise the last bit will be ignored
  activateRele(rele_2, sleep_time_read); // Move the head one step back otherwise there will be one digit more
  display_option(3); // Show "Write complete!"
  delay(1000); // Display message for 1 second
}
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

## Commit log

2026-01-10 2026_01_10 First Release
    [Circuit_scheme.fzz, Pinout_Attuation.xls]
2026-01-11 2026_01_11 add arduino/example/4_write_read_bit
    [Circuit_scheme.fzz]
2026-01-12 2026_01_12 add arduino/example/4_write_read_bit/photos
2026-01-17 2026_01_17 add arduino/example/5_write_read_sequence
    [Circuit_scheme.fzz]
2026-01-31 2026_01_31 add arduino/example/6_write_read_with_display
    [Circuit_scheme.fzz]
2026-02-01 2026_02_01 add and update arduino/example/ from 1 to 7
    [Circuit_scheme.fzz]
2026-02-01 2026_02_01 add and update arduino/example/8_write_read_display_keypad_PCF8574
    [Circuit_scheme.fzz]
2026-02-01 2026_02_01 add and update arduino/example/8_... pinout update
